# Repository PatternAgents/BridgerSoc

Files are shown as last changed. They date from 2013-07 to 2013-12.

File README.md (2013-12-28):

BridgerSoc
=============

[PatternAgents BridgerSoc  
*PatternAgents BridgerSoc*](http://www.patternagents.com/projects/BridgerSoc.html)

PatternAgents The BridgerSoc uses a Programmable System-on-Chip that can read read inputs from sensors, 
switches, potentiometers, or other analog inputs and use those inputs to control the outputs of your choice.

Features:

  System-on-Chip Standalone Mode (Switches/Analog Inputs Control the Outputs)

  Arduino Uno/Leonardo/Mega/Due Compatible Shield

  Selectable 3.3Volt-5.0Volt Operation

  Sixteen (16) high power darlington control outputs

  Seven (7) analog inputs (sensors, potentiometers)

  Five (5) digital inputs (switches, sensors)

  UART, I2C, SPI, RS-485/DMX Interfaces

  Selectable mode of operation  (Manual or Interface/Shield controlled)

You can read more about the PSoC1 Integrated Circuit used here : http://www.cypress.com/?mpn=CY8C29566-24AXI

[  
*Licensing CC BY-NC-SA 4.0*](http://creativecommons.org/licenses/by-nc-sa/4.0/)

PatternAgents uses the increasingly popular business model called "Dual Licensing" 
in which both the open source software distribution mechanism and traditional commercial software distribution models are combined.

Open Source Projects:        

If you are developing and distributing open source applications under the Creative Commons CC BY-NC-SA 4.0, 
as published by the Creative Commons Foundation, then you are free to use the PatternAgents hardware/software under the CC BY-NC-SA 4.0 license. 
Please note that CC BY-NC-SA 4.0 requires that all modifications to the original code as well as all Derivative Works 
must also be released under the terms of the CC BY-NC-SA 4.0 license.

Closed Source Projects:

If you are developing and distributing traditional closed source or commercial applications, 
you must purchase a PatternAgents commercial use license, 
which is specifically designed for users interested in retaining the proprietary status of their designs and code. 
All PatternAgents commercial licenses expressly supersede the CC BY-NC-SA 4.0 license. 
This means that when you license the PatternAgents software under a commercial license, 
you specifically do not use the software under the CC BY-NC-SA 4.0 license and therefore you are not subject to any of its terms.
        
If you would like to use our designs for your own personal or educational use, have at it! 

Our public design repository is available at <a href="https://github.com/patternagents">Github</a>.

If you would like to produce our designs for commercial use, or as products for sale, 
please contact us to arrange for a Commercial Use license. We have many other designs, 
as well as options and extras that are not released publicly. 
We will also customize designs, firmware, and software for a reasonable fee, just contact us to discuss your requirements.

THIS SOFTWARE IS PROVIDED BY THE CONTRIBUTORS "AS IS" AND WITHOUT ANY EXPRESS OR IMPLIED WARRANTIES, 
INCLUDING, BUT NOT LIMITED TO, THE IMPLIED WARRANTIES OF MERCHANTABILITY AND FITNESS FOR A PARTICULAR PURPOSE ARE DISCLAIMED. 
IN NO EVENT SHALL THE COPYRIGHT OWNER OR CONTRIBUTORS BE LIABLE FOR ANY DIRECT, INDIRECT, INCIDENTAL, SPECIAL, EXEMPLARY, 
OR CONSEQUENTIAL DAMAGES (INCLUDING, BUT NOT LIMITED TO, PROCUREMENT OF SUBSTITUTE GOODS OR SERVICES; LOSS OF USE, DATA, 
OR PROFITS; OR BUSINESS INTERRUPTION) HOWEVER CAUSED AND ON ANY THEORY OF LIABILITY, WHETHER IN CONTRACT, 
STRICT LIABILITY, OR TORT (INCLUDING NEGLIGENCE OR OTHERWISE) ARISING IN ANY WAY OUT OF THE USE OF THIS SOFTWARE, 
EVEN IF ADVISED OF THE POSSIBILITY OF SUCH DAMAGE. 

-------------------------------------------------------------------------------------------

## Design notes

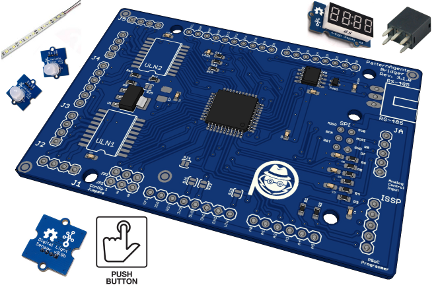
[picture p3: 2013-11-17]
BridgerSoc/images/BridgerSoc_isoc.png

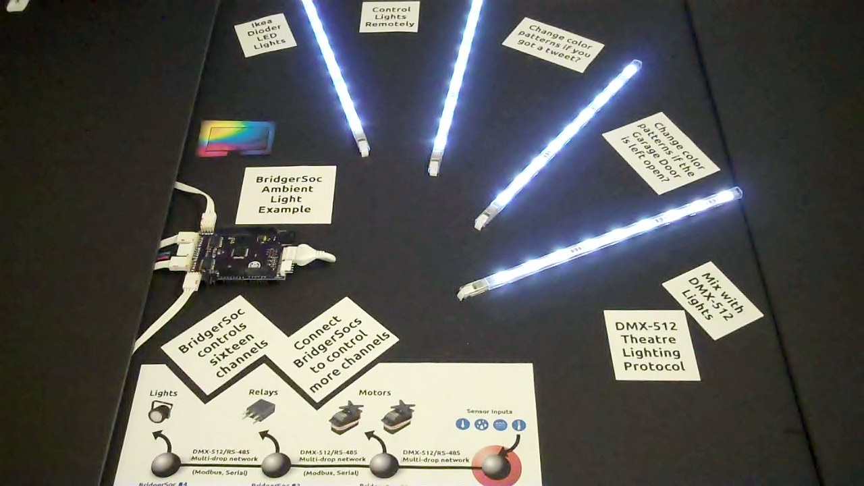
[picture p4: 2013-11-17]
BridgerSoc/images/BridgerSoc1_App2.jpg

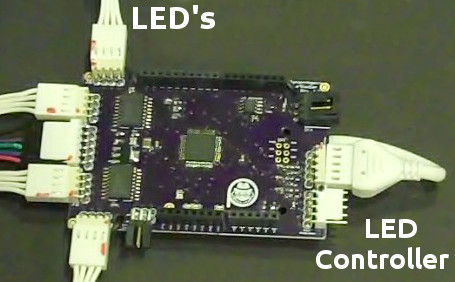
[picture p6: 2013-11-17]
BridgerSoc/images/BridgerSoc1_App1.jpg

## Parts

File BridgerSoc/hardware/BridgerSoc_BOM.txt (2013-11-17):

Partlist BridgerSoc.sch at 10/9/2013 3:49:02 PM

Part   Value              Device               Package               Description                                                                                                                                                                               MF                MPN       OC_FARNELL OC_NEWARK
PCB    PA_LEO_PATTERNMEDW PA_LEO_PATTERNMEDW   PA_LEO_MEDW_PATTERN   PatternAgents BridgerSoc PCB                                                                                                                                                                                                          
C1     0.1uF              CAP0603-CAP          0603-CAP              Capacitor                                                                                                                                                                                                                                 
C2     1uF                CAP0603-CAP          0603-CAP              Capacitor                                                                                                                                                                                                                                 
C3     1uF                CAP0603-CAP          0603-CAP              Capacitor                                                                                                                                                                                                                                 
C4     0.1uF              CAP0603-CAP          0603-CAP              Capacitor                                                                                                                                                                                                                                 
C5     1uF                CAP0603-CAP          0603-CAP              Capacitor                                                                                                                                                                                                                                 
C6     0.1uF              CAP0603-CAP          0603-CAP              Capacitor                                                                                                                                                                                                                                 
C7     10uF               CPOL-EUSMCB          SMC_B                 POLARIZED CAPACITOR, European symbol                                                                                                                                                                                                      
C8     0.1uF              CAP0603-CAP          0603-CAP              Capacitor                                                                                                                                                                                                                                 
C9     0.1uF              CAP0603-CAP          0603-CAP              Capacitor                                                                                                                                                                                                                                 
C10    0.1uF              CAP0603-CAP          0603-CAP              Capacitor                                                                                                                                                                                                                                 
FID1   FIDUCIAL1.5X3      FIDUCIAL1.5X3        FIDUCIAL-1.5X3        Fiducial Alignment Points                                                                                                                                                                                                                 
FID2   FIDUCIAL1.5X3      FIDUCIAL1.5X3        FIDUCIAL-1.5X3        Fiducial Alignment Points                                                                                                                                                                                                                 
FID3   FIDUCIAL1.5X3      FIDUCIAL1.5X3        FIDUCIAL-1.5X3        Fiducial Alignment Points                                                                                                                                                                                                                 
FID4   FIDUCIAL1.5X3      FIDUCIAL1.5X3        FIDUCIAL-1.5X3        Fiducial Alignment Points                                                                                                                                                                                                                 
ISSP                      M05PTH               1X05                  Header 5                                                                                                                                                                                                                                  
J1                        M04PTH               1X04                  Header 4                                                                                                                                                                                                                                  
J2                        M04PTH               1X04                  Header 4                                                                                                                                                                                                                                  
J3                        M06SIP               1X06                  Header 6                                                                                                                                                                                                                                  
J4                        M04PTH               1X04                  Header 4                                                                                                                                                                                                                                  
J5                        M04PTH               1X04                  Header 4                                                                                                                                                                                                                                  
JA                        M05PTH               1X05                  Header 5                                                                                                                                                                                                                                  
JP1                       M03PTH               1X03                  Header 3                                                                                                                                                                                                                                  
JP2                       M03PTH               1X03                  Header 3                                                                                                                                                                                                                                  
LED1                      LED0603              LED-0603              LEDs                                                                                                                                                                                                                                      
R1     4.7K               RESISTORR0603        R0603                 RESISTOR, American symbol                                                                                                                                                                                                                 
R2     4.7K               RESISTORR0603        R0603                 RESISTOR, American symbol                                                                                                                                                                                                                 
R3     10K                RESISTORR0603        R0603                 RESISTOR, American symbol                                                                                                                                                                                                                 
R4     1K                 RESISTORR0603        R0603                 RESISTOR, American symbol                                                                                                                                                                                                                 
R5     10K                RESISTORR0603        R0603                 RESISTOR, American symbol                                                                                                                                                                                                                 
R6     1K                 RESISTORR0603        R0603                 RESISTOR, American symbol                                                                                                                                                                                                                 
R7     10K                RESISTORR0603        R0603                 RESISTOR, American symbol                                                                                                                                                                                                                 
R8     1K                 RESISTORR0603        R0603                 RESISTOR, American symbol                                                                                                                                                                                                                 
R9     240                RESISTORR0603        R0603                 RESISTOR, American symbol                                                                                                                                                                                                                 
R10    390                RESISTORR0603        R0603                 RESISTOR, American symbol                                                                                                                                                                                                                 
R11    330                RESISTORR0603        R0603                 RESISTOR, American symbol                                                                                                                                                                                                                 
R12    4.7K               RESISTORR0603        R0603                 RESISTOR, American symbol                                                                                                                                                                                                                 
R13    4.7K               RESISTORR0603        R0603                 RESISTOR, American symbol                                                                                                                                                                                                                 
R14    1K                 RESISTORR0603        R0603                 RESISTOR, American symbol                                                                                                                                                                                                                 
RS-485 70553-02           70553-02             70553-02              Molex SL Modular Connectors - 3 PIN                                                                                                                                                                                                       
RTERM  120                RESISTOR_SFE0603-RES 0603-RES              Resistor                                                                                                                                                                                                                                  
SJ1    SOLDERJUMPERNO     SOLDERJUMPERNO       SJ_2S-NO              Solder Jumper                                                                                                                                                                                                                             
SJ2    SOLDERJUMPERNO     SOLDERJUMPERNO       SJ_2S-NO              Solder Jumper                                                                                                                                                                                                                             
SJ3    SOLDERJUMPERNO     SOLDERJUMPERNO       SJ_2S-NO              Solder Jumper                                                                                                                                                                                                                             
SJ4    SOLDERJUMPERNO     SOLDERJUMPERNO       SJ_2S-NO              Solder Jumper                                                                                                                                                                                                                             
SJ5    SOLDERJUMPERNO     SOLDERJUMPERNO       SJ_2S-NO              Solder Jumper                                                                                                                                                                                                                             
TVS1   SP1001-02JTG       SP1001-02JTG         SC70-3                Littelfuse SP1001-02JTG TVS Diode Array                                            
U1     V_REG_317SMD       V_REG_317SMD         SOT223                Voltage Regulator                                                                                                                                                                                                                         
U2     CY8C29566-44PIN    CY8C29566-44PIN      TQFP-10X10-44         Cypress PSoC® 1 - PSOC, M8C Based                                                                                                                                                                                  
U3     SN65176D           SN65176D             SO-08                 DIFFERENTIAL BUS TRANSCEIVER                                                                                                                                                              TEXAS INSTRUMENTS SN65176BD 9589970    08F5891  
ULN1                      ULN2803SOICW         SO18L                 Darlington Driver                                                                                                                                                                                                                         
ULN2                      ULN2803SOICW         SO18L                 Darlington Driver                                                                                                                                                                                                                         
JA1                       M08PTH               1X08                  Arduino1                                                                                                                                                                                                                                  
JA2                       M06PTH               1X06                  Arduino2                                                                                                                                                                                                                                  
JA3                       M08PTH               1X08                  Arduino3                                                                                                                                                                                                                                  
JA4                       M10PTH               1X10                  Arduino4

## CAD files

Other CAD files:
BridgerSoc/eagleUp/BridgerSoc.skp

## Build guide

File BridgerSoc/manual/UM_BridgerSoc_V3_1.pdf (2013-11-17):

BridgerSoc1—Getting Started Guide

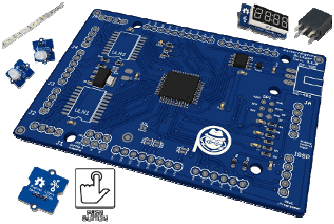
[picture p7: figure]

Page 1 | www.patternagents.com

## BridgerSoc1

## Getting Started Guide

Copyright 2011, 2012, 2013 www.patternagents.com

http://www.patternagents.com/products.html

Revision 3.1.11
PCD #272A

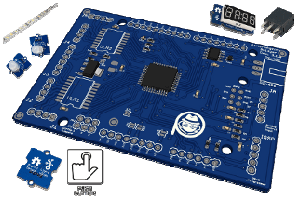
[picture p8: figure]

Page 2 | www.patternagents.com

## BridgerSoc1

Overview | 2
Getting Started | 2
Operating Modes | 6
Schematic and Layout | 14
PSoC Pin Assignment | 20
BridgerSoc1 PCB Pin Assignment | 21
Custom Configuration Jumpers | 22
Frequently Asked Questions (FAQ) | 24
Example Project | 12

Contents :

Page 3 | www.patternagents.com

### Congratulations on your purchase of the “BridgerSoc1” board!

### The PatternAgents “BridgerSoc1” board has the following features :

### - System-on-Chip Standalone Mode (Switches/Analog Inputs Control the Outputs)

### - Arduino Uno/Leonardo/Mega/Due Compatible Shield

### - Selectable 3.3Volt-5.0Volt Operation

### - Sixteen (16) high power darlington control outputs

### - Seven (7) analog inputs (sensors, potentiometers)

### - Five (5) digital inputs (switches, sensors)

### - UART, I2C, SPI, RS-485/DMX Interfaces

### - Selectable mode of operation (Manual or Interface/Shield controlled)

### Overview :

BridgerSoc1 has sixteen (16) programmable digital blocks, and twelve (12)
progammable analog blocks that come pre-programmed for a variety of uses, so it is ready to use right out of the box. It also includes a Command Line Interface (CLI) that gives you the ability to control it right from a terminal or the programming language of your choice, mak-ing it very easy to get started.
Using a set of configuration jumpers, you can interface to the BridgerSoc1 using
simple switches or sensors, so anyone can use it without having to learn how to
program. If you want to control Bridger from a program you can use the UART (CLI), I2C/Two-Wire Bus, or the SPI interface - giving you the maximum flexibility to configure your other shields without I/O conflicts.

Stack-Thru Models (optional request):
As an option, PatternAgents “BridgerSoc1” boards can populated with “Stack-Thru” connectors, which allow Arduino Shields to be added to the top or bottom of the Arduino board stack.

NOTE: Always make sure the stacking pins don’t contact a metal surface (like a metal table).

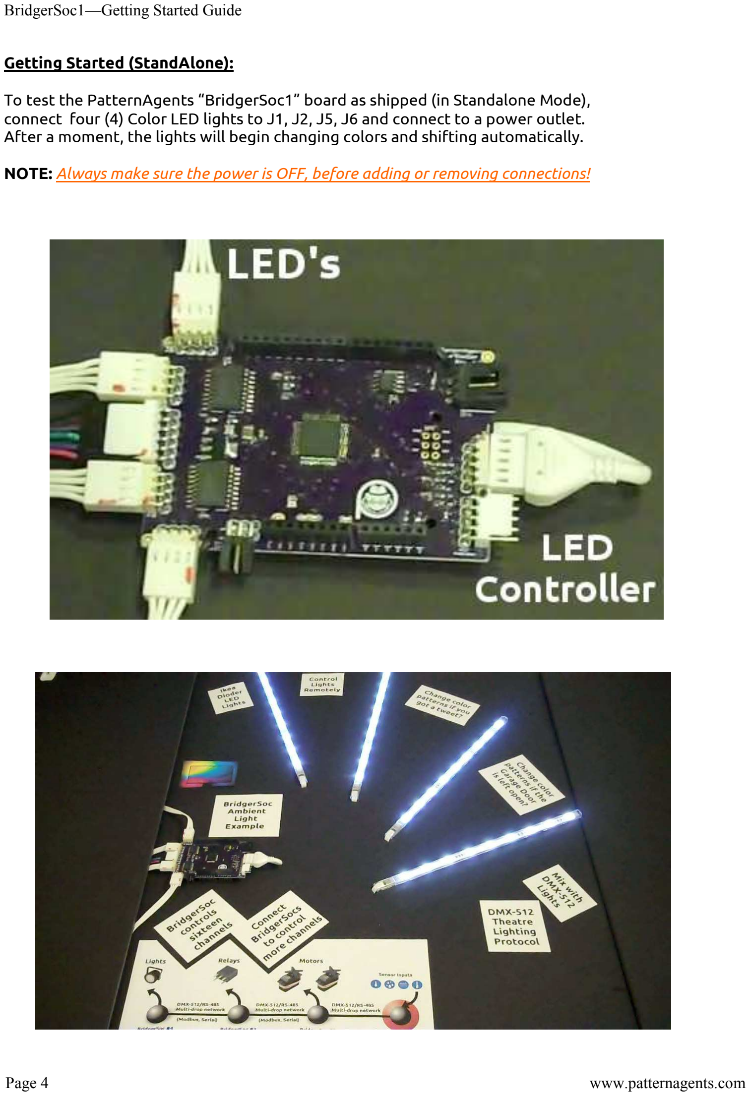
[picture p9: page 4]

Page 4 | www.patternagents.com

Getting Started (StandAlone):

To test the PatternAgents “BridgerSoc1” board as shipped (in Standalone Mode), connect four (4) Color LED lights to J1, J2, J5, J6 and connect to a power outlet. After a moment, the lights will begin changing colors and shifting automatically.

NOTE: Always make sure the power is OFF, before adding or removing connections!

Page 5 | www.patternagents.com

Getting Started (Arduino):

To connect the PatternAgents “BridgerSoc1” board to an Arduino CPU, carefully align the pins between the two boards and gently press together to connect.

NOTE: Always make sure the power is OFF, before adding or removing connections!

Arduino Serial Mode (Mode 0);

Make sure that all three (3) jumpers are connected between JP1 and JP2 to select Mode 0. Connect the Arduino USB interface to your host computer and open a “Hyper-terminal” or other Terminal emulation program to the serial port for your Arduino (COMx:).
Set the Terminal emulation program to 9600 Baud , N, 8, 1 (which is usually the default).
Set the Terminal emulation program to “Echo” so that you can see the characters typed.

The Sixteen Lighting Channels reside from a default DMX address of 40 to 55 (decimal). So the User would set the lighting channels all to maximum brightness using :

> <DMX> 40 255<CR>
> <DMX> 41 255<CR>
> <DMX> 42 255<CR>
> ...
> <DMX> 55 255<CR>

To read the setting of a DMX channel, just use the question mark for data : > <DMX> 40 ?<CR>

and the BridgerSoc1 will respond :
> <DMX> 40 255<CR>

CLI Help : (enter ?)

> ?
Help Topics
——————-
…

Page 6 | www.patternagents.com

BridgerSoc1 Operating Modes :

The BridgerSoc1 has three (3) Configuration Jumpers which select one (1) of eight (8) operating modes, namely :

0 : 000 : UART CLI Mode
1 : 001 : I2C Arduino Mode
2 : 010 : I2C Leonardo Mode
3 : 011 : SPI Mode
4 : 100 : Test Mode
5 : 101 : DMX-512 Slave Mode
6 : 110 : Bike Light Mode : (Run/Stop/Left-Turn/Right-Turn) 7 : 111 : Standalone Mode - Dioder Manual Control

The Configuration Jumpers are labeled JP1/JP2, pins 1 thru 3.
The BridgerSoc1 is shipped in “Test Mode (4)” so that it automatically Starts changing the lighting colors in a shifting pattern.

Page 7 | www.patternagents.com

BridgerSoc1 Operating Mode O : UART CLI Mode :

# Mode 0 - UART CLI Mode

# In this mode the BridgerSoc1 communicates with a host using a # Command Line Interface via a UART serial interface,

# using Arduino Pins D0 (TXD) & D1 (RXD)

# The Arduino default of 9600 Baud, 8 Bits, No Parity, 1 Stop Bit is used.

# Open a “HyperTerminal” or other program interface to the Arduino serial Port.

# The Sixteen Lighting Channels reside from a default DMX address of 40 to 55 (decimal). # So the User would set the lighting channels all to maximum brightness using :

# | > <DMX> 40 255<CR>

# | > <DMX> 41 255<CR>

# | > <DMX> 42 255<CR>

# | > ...

# | > <DMX> 55 255<CR>

# | To read the setting of a DMX channel, just use the question mark for data :

# | > <DMX> 40 ?<CR>

# | and the BridgerSoc1 will respond :

# | > <DMX> 40 255<CR>

# CLI Help : (enter ?)

# | > ?

# | Help Topics

# | ——————-

# | …

Page 8 | www.patternagents.com

BridgerSoc1 Operating Mode 1 : I2C Arduino Mode :

# Mode 1 - I2C Arduino Mode

# In this mode the BridgerSoc1 communicates with an Arduino host using # the original I2C Pins for the Arduino Uno, A4 & A5.

# The Arduino default of 400K speed I2C Bus is used.

# Open a “HyperTerminal” or other program interface to the Arduino serial Port.

# The Sixteen Lighting Channels reside from a default I2C address of 40 to 55 (decimal). # So the User would set the lighting channels all to maximum brightness using :

# | > <I2C_Write> 40 255<CR>

# | > <I2C_Write> 41 255<CR>

# | > <I2C_Write> 42 255<CR>

# | > ...

# | > <I2C_Write> 55 255<CR>

BridgerSoc1 Operating Mode 2 : I2C Leonardo Mode :

# Mode 2 - I2C Leonardo Mode

# In this mode the BridgerSoc1 communicates with an Arduino host using # the I2C Pins for the Arduino Leonardo, SCL &SDA.

# The Arduino default of 400K speed I2C Bus is used.

# Open a “HyperTerminal” or other program interface to the Arduino serial Port.

# The Sixteen Lighting Channels reside from a default I2C address of 40 to 55 (decimal). # So the User would set the lighting channels all to maximum brightness using :

# | > <I2C_Write> 40 255<CR>

# | > <I2C_Write> 41 255<CR>

# | > <I2C_Write> 42 255<CR>

# | > ...

# | > <I2C_Write> 55 255<CR>

Page 9 | www.patternagents.com

BridgerSoc1 Operating Mode 3 : SPI Mode :

# Mode 3 - SPI Mode

# In this mode the BridgerSoc1 communicates with an Arduino host using

# the SPI Pins for the Arduino Leonardo, P13, P12, P11, & P10.

# The Sixteen Lighting Channels reside from a default SPI address of 40 to 55 (decimal). # So the User would set the lighting channels all to maximum brightness using :

# | > <SPI_Write> 40 255<CR>

# | > <SPI_Write> 41 255<CR>

# | > <SPI_Write> 42 255<CR>

# | > ...

# | > <SPI_Write> 55 255<CR>

BridgerSoc1 Operating Mode 4 : Test Mode :

# Mode 4 - Test Mode

# | In this mode the BridgerSoc1 operates standalone,

# | and cycles random colors through all of the lighting channels.

# The BridgerSoc1 will ignore all other inputs in this mode.

Page 10 | www.patternagents.com

BridgerSoc1 Operating Mode 5 : DMX-512 Slave Mode :

# Mode 5 - DMX-512 Slave Mode

# In this mode the BridgerSoc1 communicates with a DMX-512 Universe/Host using # the DMX-512/RS-485 connector, labeled “DMX-512”.

# The DMX-512 default of 250k Baud, 8 Bits, No Parity, 1 Stop Bit is used.

# The Sixteen Lighting Channels reside from a default DMX address of 40 to 55 (decimal). # So the User would set the lighting channels all to maximum brightness using :

# | > <DMX> 40 255<CR>

# | > <DMX> 41 255<CR>

# | > <DMX> 42 255<CR>

# | > ...

# | > <DMX> 55 255<CR>

Page 11 | www.patternagents.com

BridgerSoc1 Operating Mode 6 : DMX-512 Slave Mode :

# Mode 6 - Bike Light Controller Mode

# In this mode the BridgerSoc1 reads a number of input switches, # located on the handlebars or the steering wheel column of a

# Light Electric Vehicle (LEV),

# via the D12/D11/D10/A3/A2/A1/A0 pin inputs.

# The control inputs have internal pullup resistors,

# so that a switch closed (on) should connect them to ground. #

# Handlebar Switch mapping is as follows :

# | Arduino | Pin Function | PSoC

# | Pin | Pin

# | D13 | : Arduino LED (input) P1_3

# | D12 | : Run Light/On Switch P4_1

# | D11 | : Horn Pushbutton | P2_1

# | D10 | : Mode Pushbutton | P2_7

# | A3 | : Right Turn Switch | P0_2

# | A2 | : Left Turn Switch | P0_3

# | A1 | : Brake Switch | P0_5

# | A0 | : Throttle/ADC Input | P0_4

# | LED Light output Mapping is as follows :

# | J1 | : Left Rear Running/Turn LED

# | J2 | : Left Front Running/Turn LED

# | J3 | : Front Headlight/Body LEDs

# | J4 | : Ikea Color Wheel Controller Input

# | J5 | : Right Front Running/Turn LED

# | J6 | : Right Rear Running/Turn LED

# In this mode, all other inputs are ignored, the physical switches control the lights. #

BridgerSoc1 Operating Mode 7 : Manual Controller Mode :

# Mode 7 - Manual Controller Mode

# In this mode the BridgerSoc1 is controlled by the Ikea Dioder Manual Control/Box, # which include it’s built-in color changing programs.

Page 12 | www.patternagents.com

BridgerSoc1— Example Project :

(Coming…)

Page 13 | www.patternagents.com

BridgerSoc1— Example Project :

(Coming…)

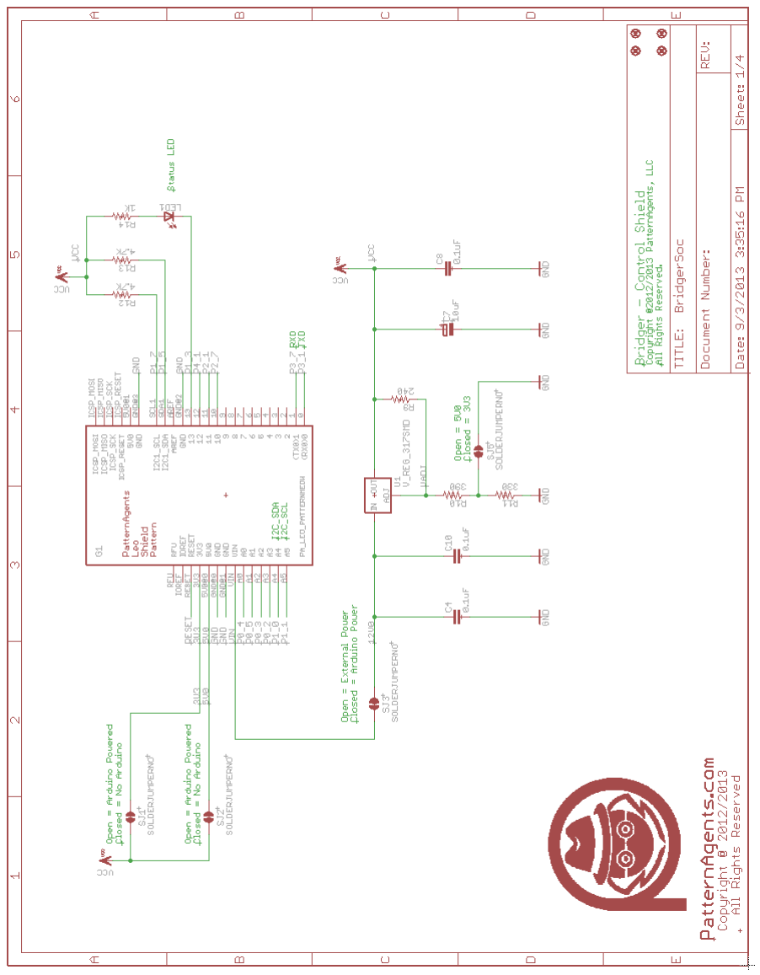
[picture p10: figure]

Page 14 | www.patternagents.com

### BridgerSoc1—Schematic Drawings

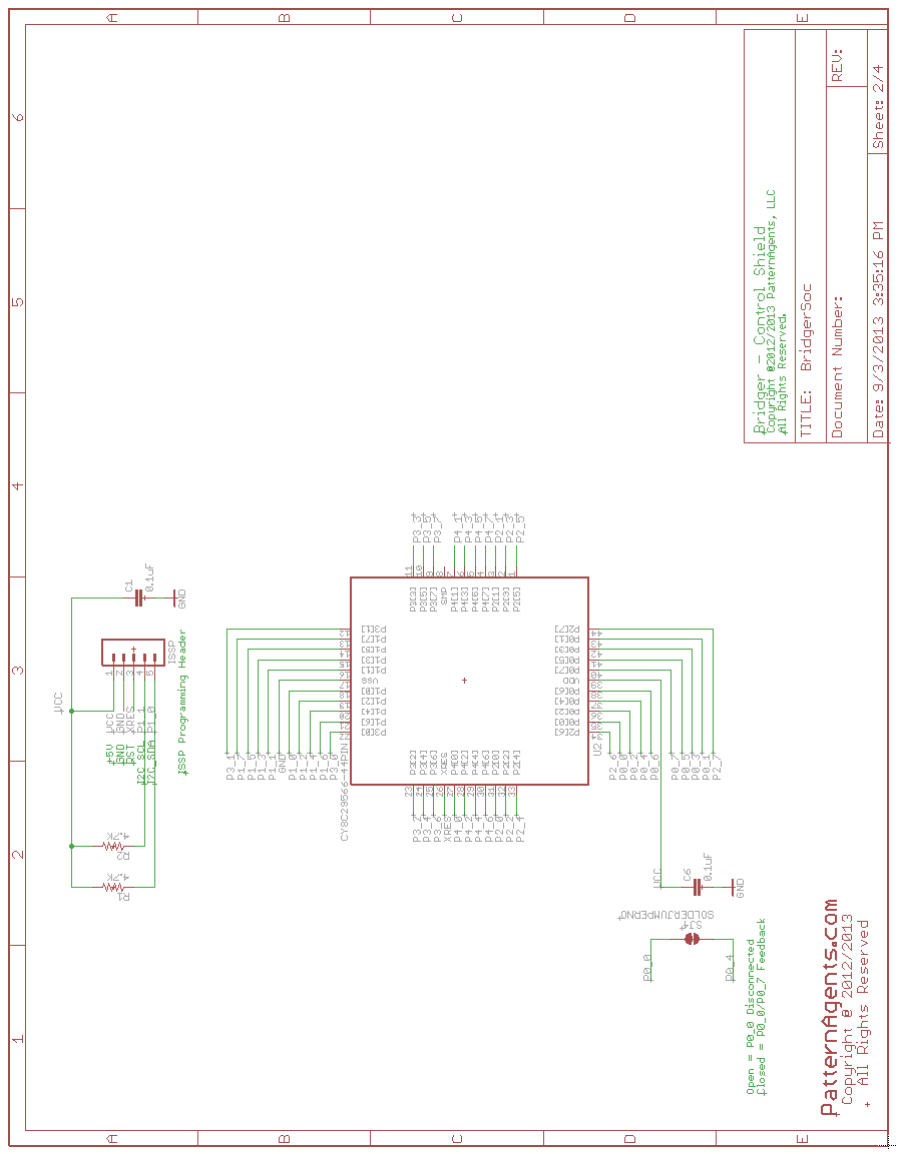
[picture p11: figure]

Page 15 | www.patternagents.com

### BridgerSoc1—Schematic Drawings

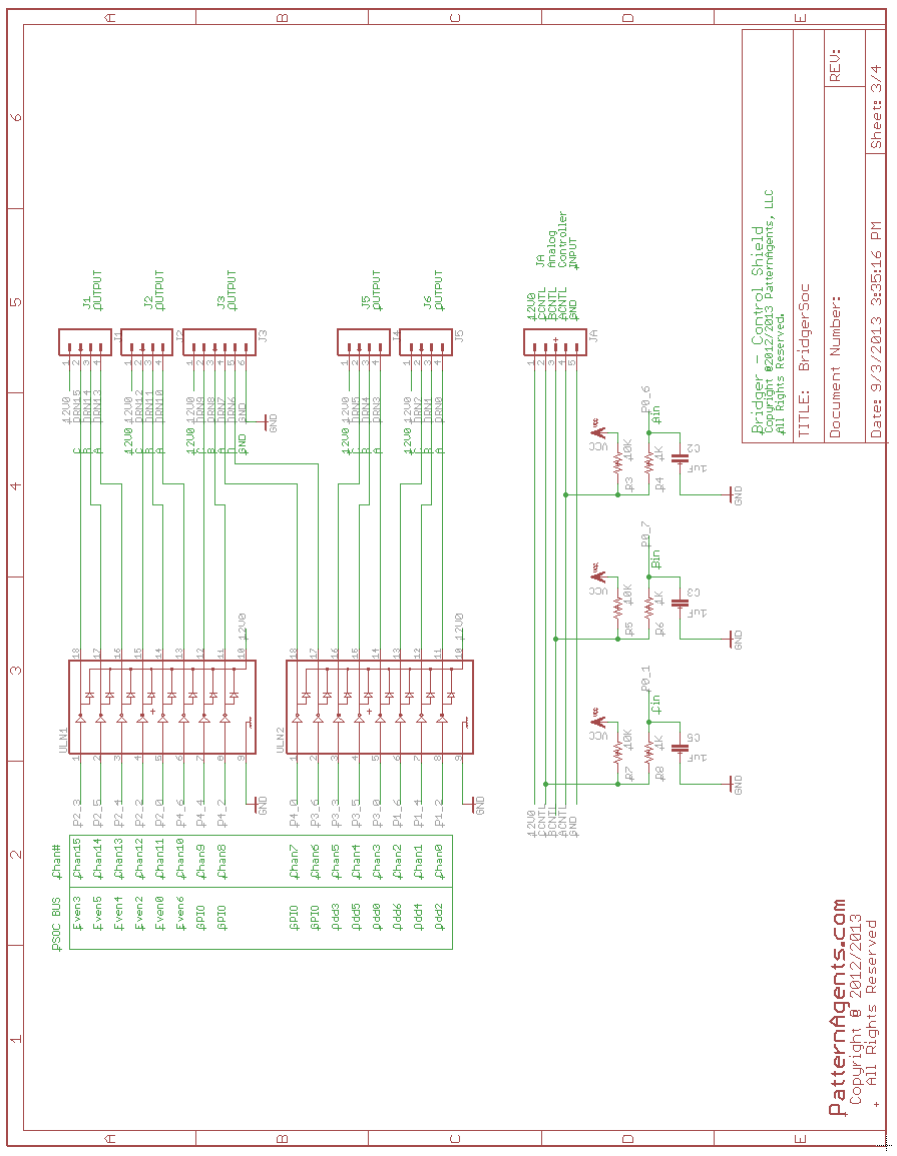
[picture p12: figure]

Page 16 | www.patternagents.com

### BridgerSoc1—Schematic Drawings

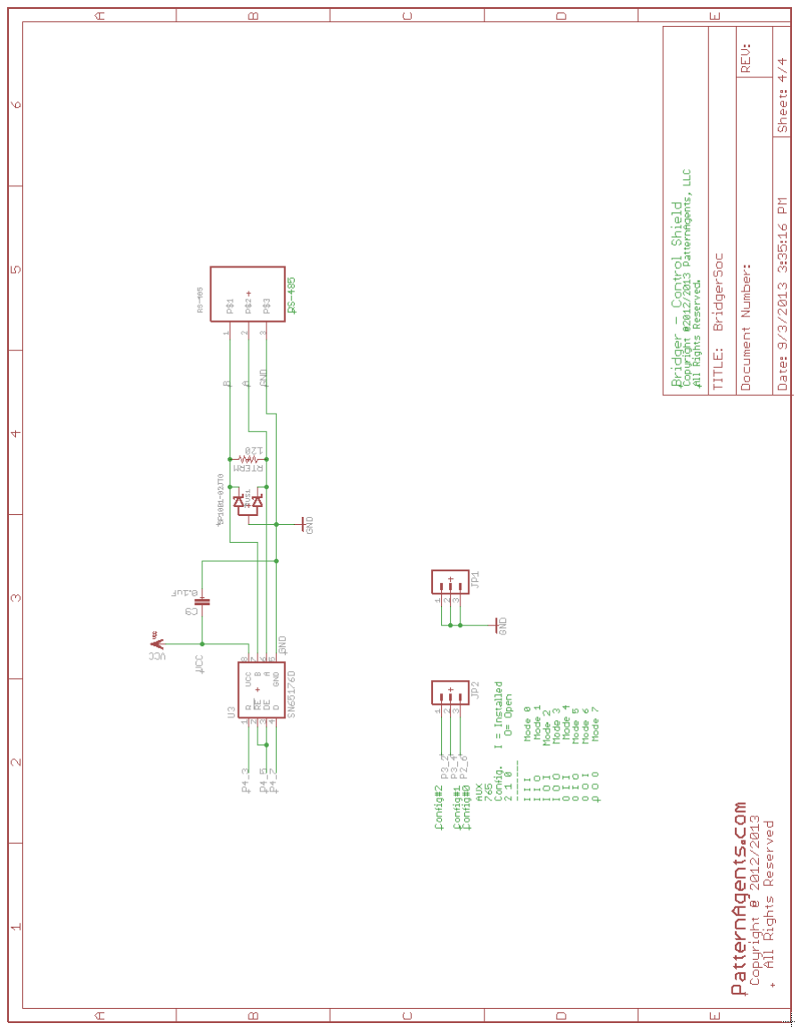
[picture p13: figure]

Page 17 | www.patternagents.com

### BridgerSoc1—Schematic Drawings

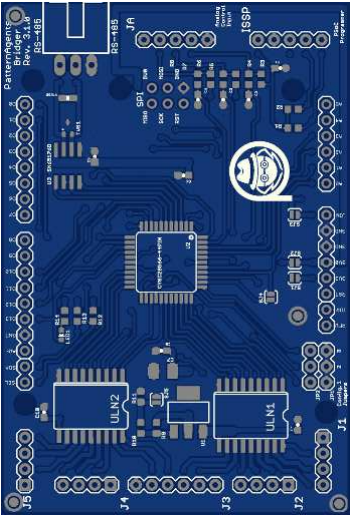
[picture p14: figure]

Page 18 | www.patternagents.com

### BridgerSoc1—PCB Top View

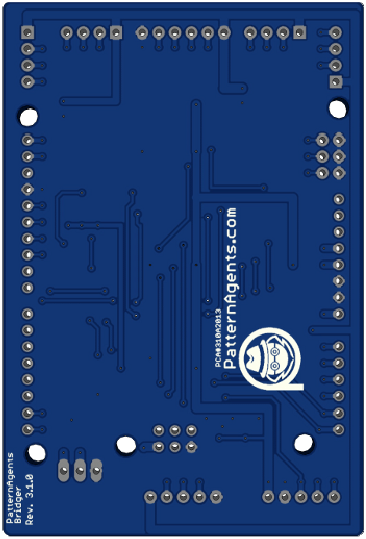
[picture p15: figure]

Page 19 | www.patternagents.com

### BridgerSoc1—PCB Bottom View

Page 20 | www.patternagents.com

BridgerSoc1— PSoC I/O Pin Assignment :

# Pin Assignments :

# Pin P0.0 ( 0 ) - SJ4/P0_4 Feedback (RFU) # Pin P0.1 ( 1 ) - Green Manual Control

# Pin P0.2 ( 2 ) - A3

# Pin P0.3 ( 3 ) - A2

# Pin P0.4 ( 4 ) - A0

# Pin P0.5 ( 5 ) - A1

# Pin P0.6 ( 6 ) - Red Manual Control # Pin P0.7 ( 7 ) - Blue Manual Control

# Pin P1.0 ( 8 ) - ISSP/I2C-SDA/A4 # Pin P1.1 ( 9 ) - ISSP/I2C-SCL/A5

# Pin P1.2 ( 10 ) - LED0/SSDM0

# Pin P1.3 ( 11 ) - D13/LED_D13

# Pin P1.4 ( 12 ) - LED1/SSDM1

# Pin P1.5 ( 13 ) - I2C-SDA

# Pin P1.6 ( 14 ) - LED2/SSDM2 # Pin P1.7 ( 15 ) - I2C-SCL

# Pin P2.0 ( 16 ) - LED11/SSDM11 # Pin P2.1 ( 17 ) - D11

# Pin P2.2 ( 18 ) - LED12/SSDM12 # Pin P2.3 ( 19 ) - LED15/SSDM15 # Pin P2.4 ( 20 ) - LED13/SSDM13 # Pin P2.5 ( 21 ) - LED14/SSDM14 # Pin P2.6 ( 22 ) - CFG3

# Pin P2.7 ( 23 ) - D10

# Pin P3.0 ( 24 ) - LED3/SSDM3 # Pin P3.1 ( 25 ) - D0/UART1-TXD # Pin P3.2 ( 26 ) - CFG1

# Pin P3.3 ( 27 ) - LED5/SSDM5 # Pin P3.4 ( 28 ) - CFG2

# Pin P3.5 ( 29 ) - LED4/SSDM4 # Pin P3.6 ( 30 ) - LED6

# Pin P3.7 ( 31 ) - D1/UART1-RXD #

# Pin P4.0 ( 32 ) - LED7

# Pin P4.1 ( 33 ) - D12

# Pin P4.2 ( 34 ) - LED8

# Pin P4.3 ( 35 ) - DMX-TXD

# Pin P4.4 ( 36 ) - LED9

# Pin P4.5 ( 37 ) - DMX-DIR

# Pin P4.6 ( 38 ) - LED10/SSDM10 # Pin P4.7 ( 39 ) - DMX-RXD

Page 21 | www.patternagents.com

BridgerSoc1— PCB Pin Assignment :

J1/J2/J4/J5 | Pin# | 1—VIN (12 VDC) 2—Green LED Output 3– Blue LED Output 4—Red LED Output
J3 | Pin# | 1—VIN (12 VDC) 2—Green LED Output 3– Blue LED Output 4—Red LED Output 5—Yellow/White LED Output 6—Ground
JA | Pin# | 1—VIN (12 VDC) 2—Green LED In 3– Blue LED In 4—Red LED In 5—Ground

RS-485/DMX-512
| Pin# | 1– B 2—A 3—Ground

Page 22 | www.patternagents.com

I/O Configuration :

BridgerSoc1 I/O Voltage Configuration :
The BridgerSoc1 boards have the ability to configure I/O signals for different voltage levels, and can be configured for either 3.3V or 5.0V volt levels. It is important to determine if your Arduino re-quires 3.3V or 5.0V volt levels, and configure your BridgerSoc1 board correctly. Refer to the manual for your Arduino board for the correct voltage settings.

Solder Jumper J5 Installed—3.3V operation
Solder Jumper J5 Removed—5.0V operation (factory default setting)

NOTE: Always make sure voltages are set correctly for your Arduino shield or you can damage it.

External VIN/5V0/3V3 Power Configuration :

The BridgerSoc1 can either get it power from an Arduino CPU, or have it’s own power supplied independently. This allows the BridgerSoc1 power input to be different than the Arduino VIN.
The default setting is that no power is connected to the Ardunio (they are independently powered). In order to change those setting, install solder jumpers as follows :

Solder Jumper J3 Installed—Arduino and BridgerSoc1 share VIN
Solder Jumper J3 Removed—Arduino and BridgerSoc1 have separate VIN

Solder Jumper J2 Installed—Arduino and BridgerSoc1 share 5.0V power
Solder Jumper J2 Removed—Arduino and BridgerSoc1 have separate 5.0V power

Solder Jumper J1 Installed—Arduino and BridgerSoc1 share 3.3V power
Solder Jumper J1 Removed—Arduino and BridgerSoc1 have separate 3.3V power

NOTE: Install either J1 or J2 , but not both, that would short 3.3v and 5V together.

Page 23 | www.patternagents.com

(This page intentionally left blank)

FAQ :

1) Can I use the “BridgerSoc1” with an “Arduino” CPU Board?

Yes. Any “Host” Arduino CPU board can be connected on the top/bottom side of the “BridgerSoc1” Board depending on what connector you install
(i.e. female only, or stack-through connectors). This allows for multi-CPU/multi-processor/ multiple architecture (i.e. big/little) configurations.

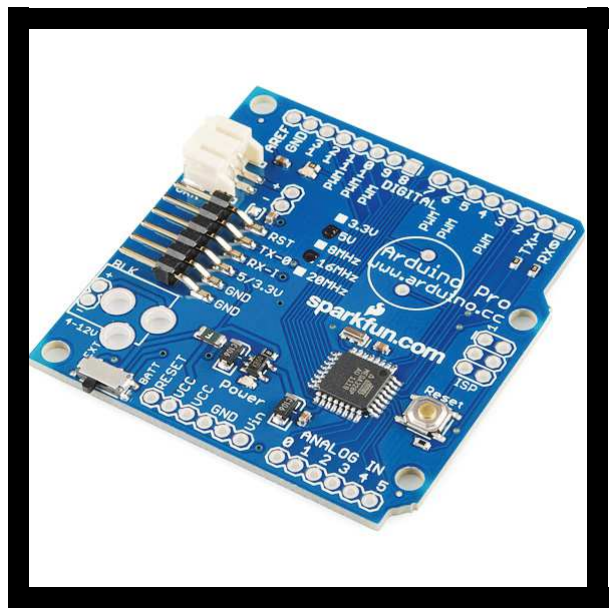
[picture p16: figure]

2) Can I use the “BridgerSoc1” with “Arduino” prototyping supplies ?

Yes. Any Arduino prototyping board can be connected on the top/bottom side of the “CPM-S to Ardu ino Shield Adaptor” Board depending on what connectors you install (i.e. male/female only, or stack- through).

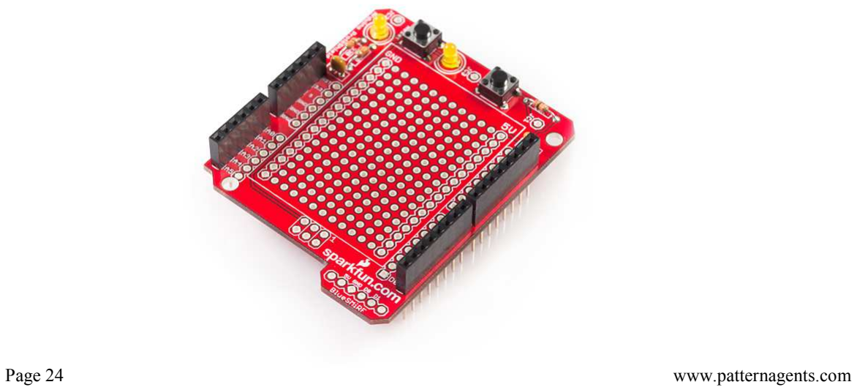
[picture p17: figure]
Page 24; www.patternagents.com

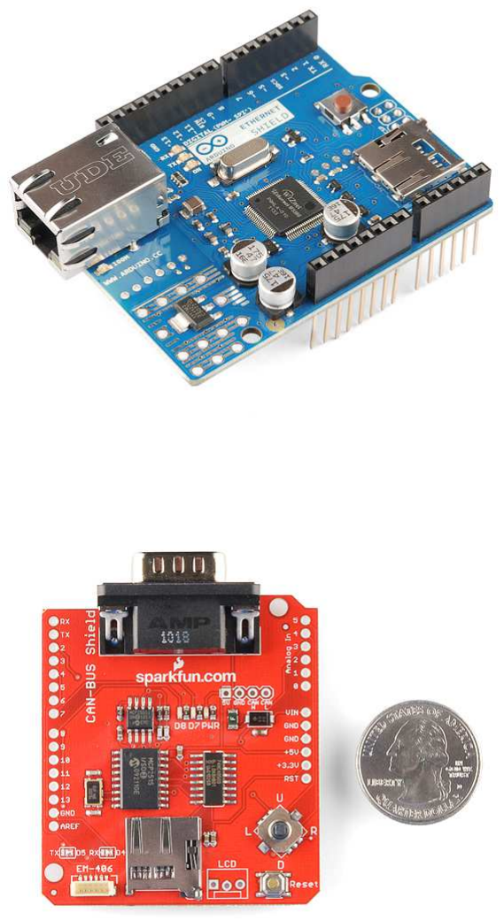
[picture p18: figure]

Page 25 | www.patternagents.com
5) Can I use the “BridgerSoc1” with other “Arduino” shields ?

Yes. (Almost) any Arduino shield board can be connected on the top/bottom side of the “BridgerSoc1” Board depending on what connectors you install
(i.e. male/female only, or stack-through)

Arduino Ethernet Shield :

Image from :
https://www.sparkfun.com/products/9026

Arduino CAN-BUS Shield :

Image from :
https://www.sparkfun.com/products/10039

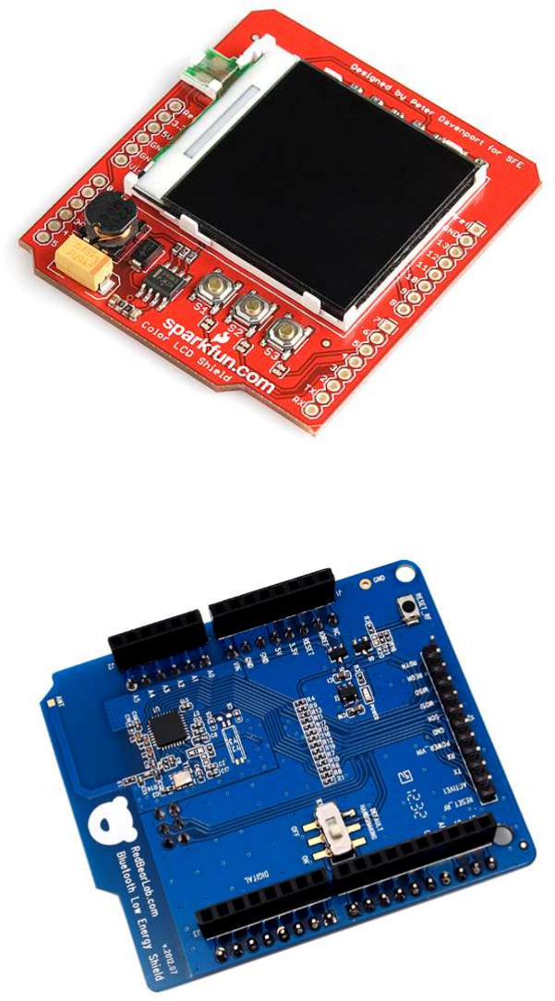
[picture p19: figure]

Page 26 | www.patternagents.com

Arduino Color LCD Shield :

Image from :
https://www.sparkfun.com/products/9363

provides an easy method of connecting the popular Nokia 6100 LCD to your PSoC.

Arduino BlueTooth LE Shield :

Image from :
https://www.seedstudio.com

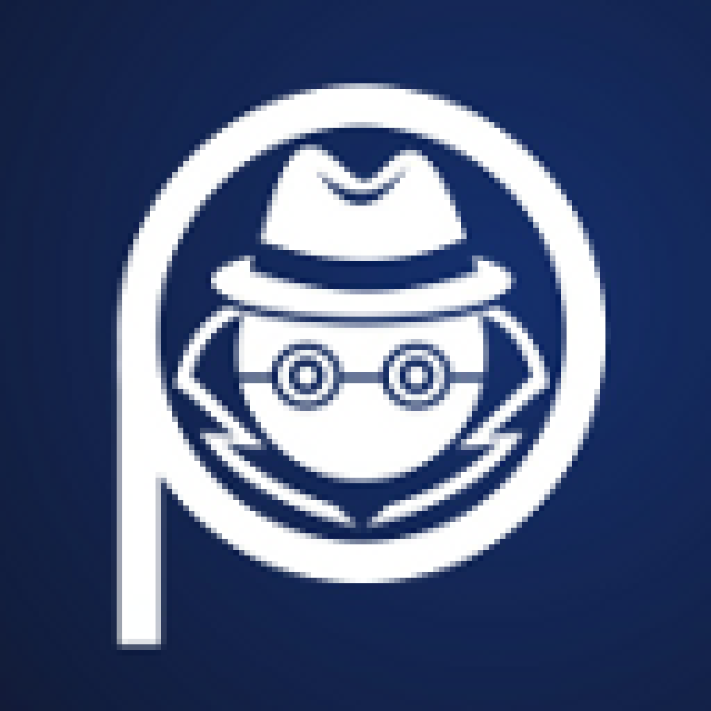
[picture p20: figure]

Page 27 | www.patternagents.com Copyright 2011, 2012, 2013 www.patternagents.com

# PatternAgents provides community and commerce for electronics designers so that they can collaborate using shared

design patterns, practices, and resources; connect with others in the industry, conceptualize and create new ideas,

# commercialize their designs, and keep up

on the latest technologies and concepts.

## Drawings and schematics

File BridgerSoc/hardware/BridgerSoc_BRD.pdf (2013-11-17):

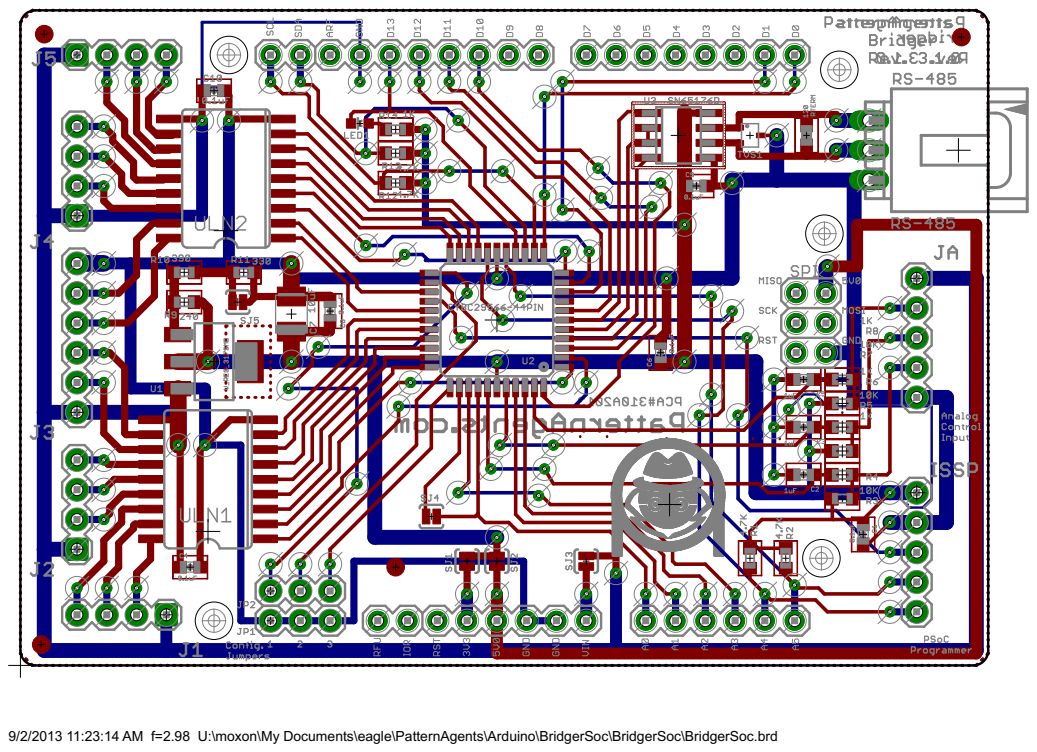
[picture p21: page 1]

9/2/2013 11:23:14 AM f=2.98 U:\moxon\My Documents\eagle\PatternAgents\Arduino\BridgerSoc\BridgerSoc\BridgerSoc.brd

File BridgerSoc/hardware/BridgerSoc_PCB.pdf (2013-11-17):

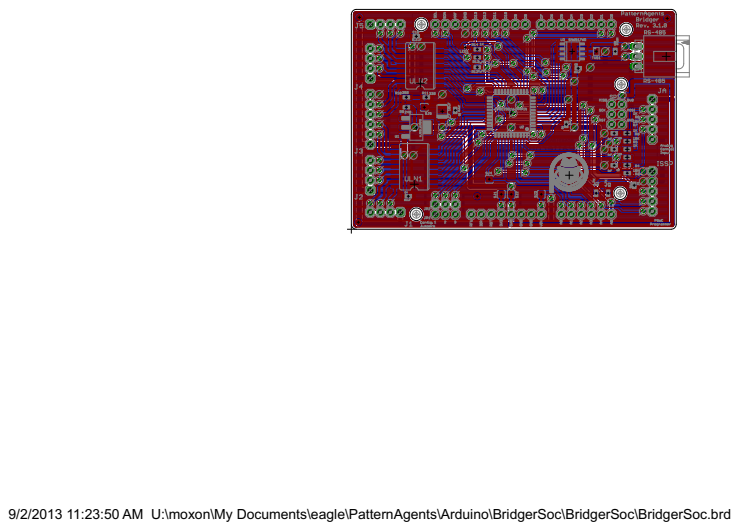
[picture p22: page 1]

9/2/2013 11:23:50 AM U:\moxon\My Documents\eagle\PatternAgents\Arduino\BridgerSoc\BridgerSoc\BridgerSoc.brd

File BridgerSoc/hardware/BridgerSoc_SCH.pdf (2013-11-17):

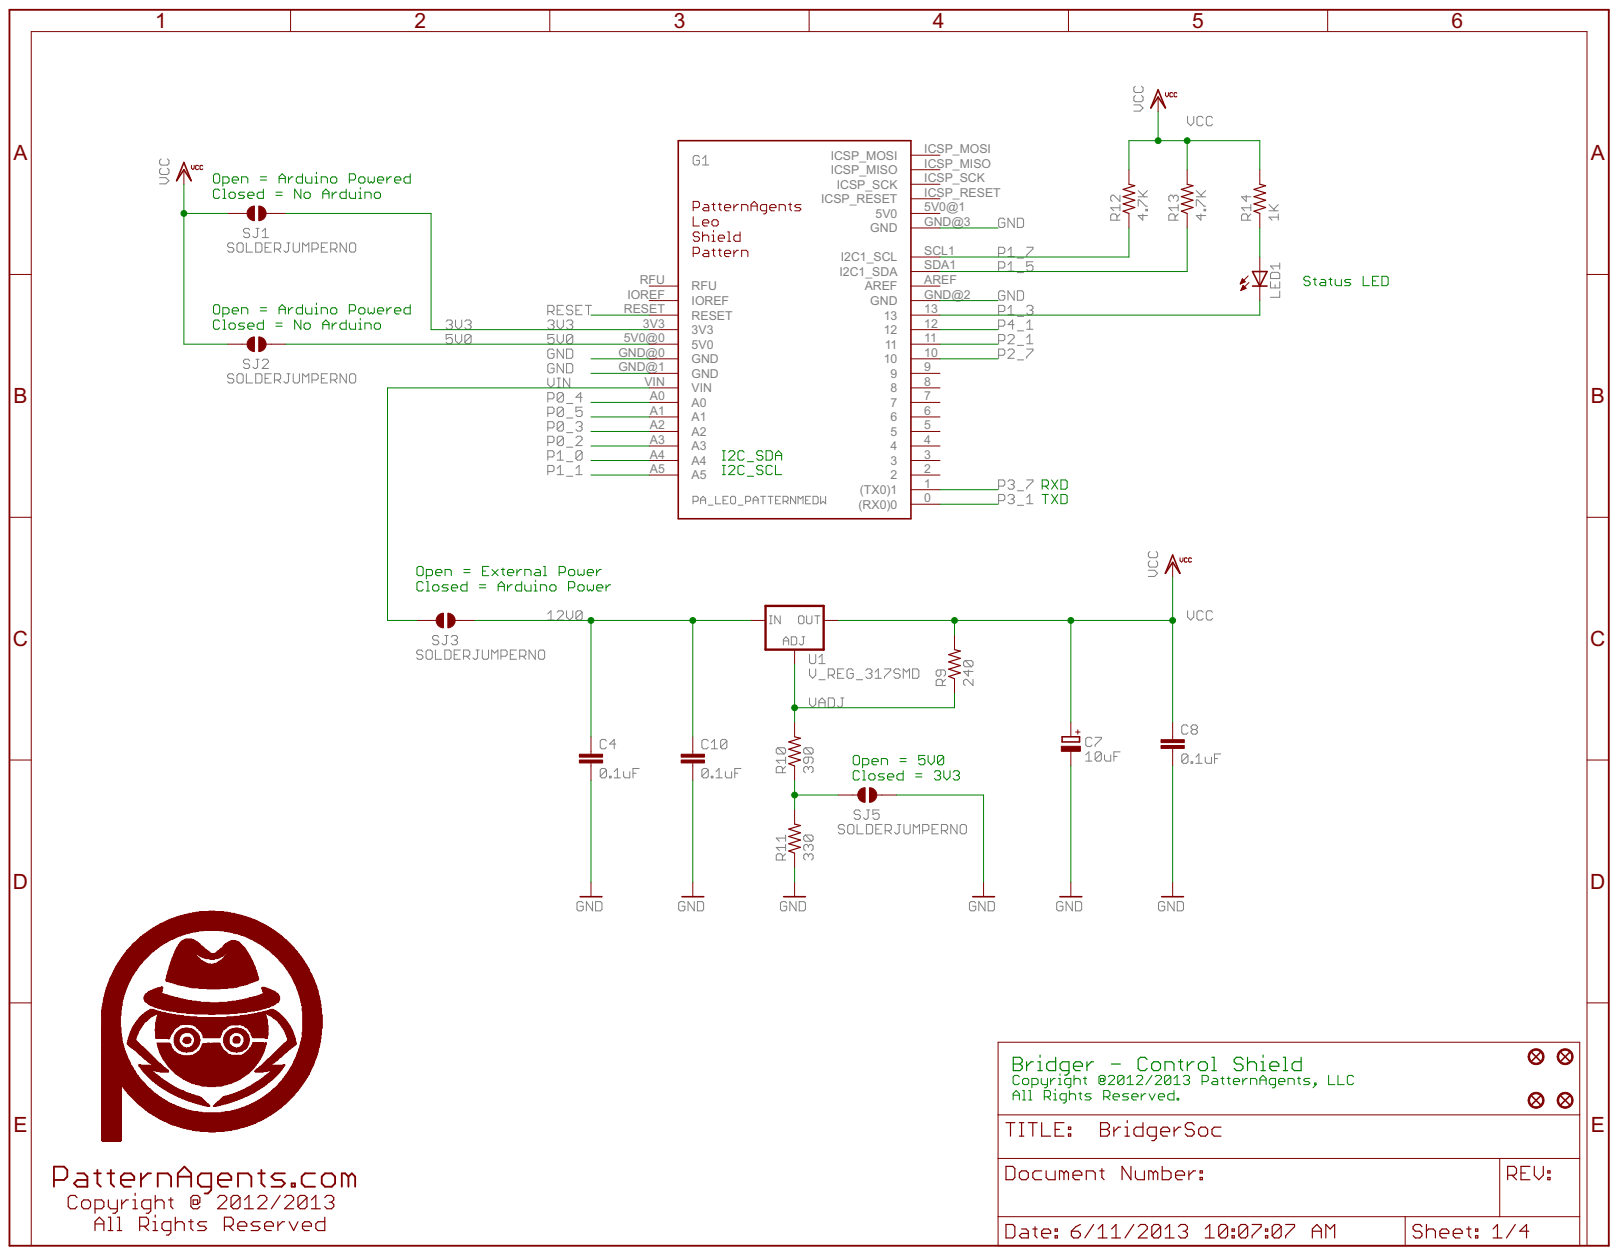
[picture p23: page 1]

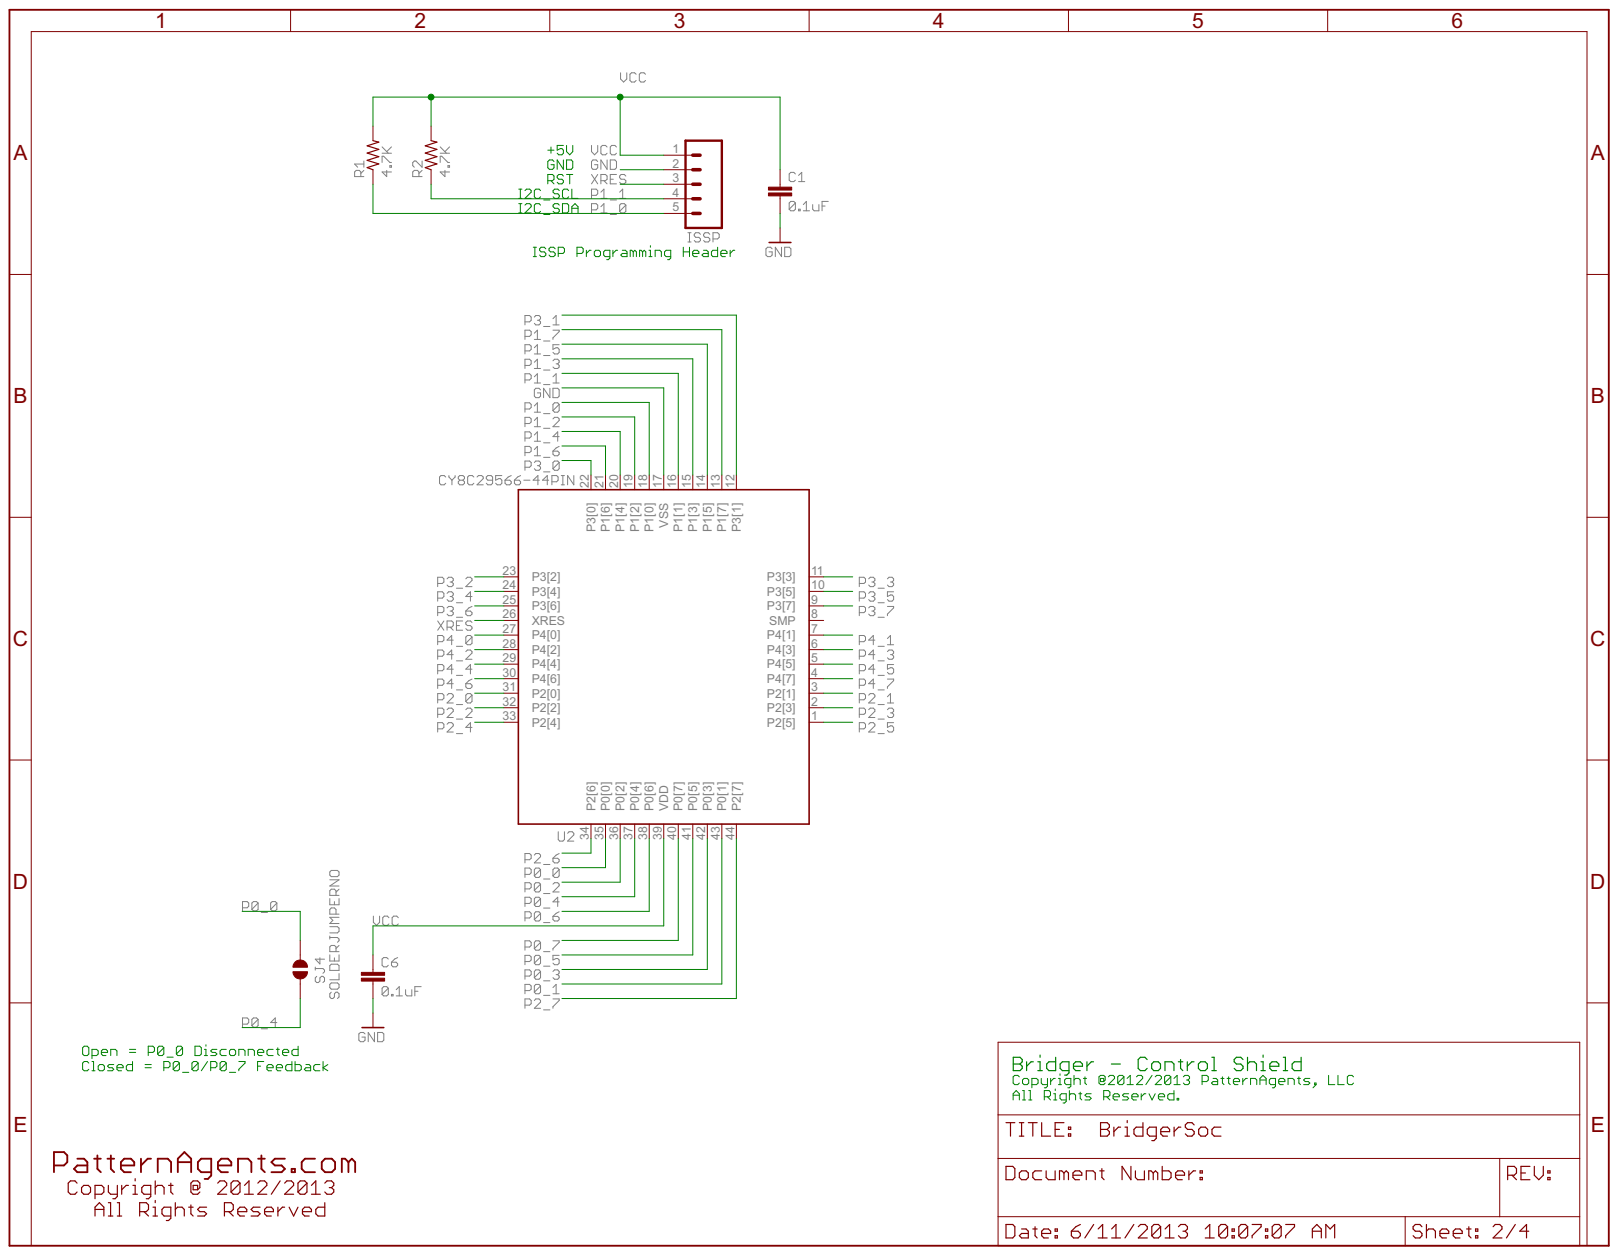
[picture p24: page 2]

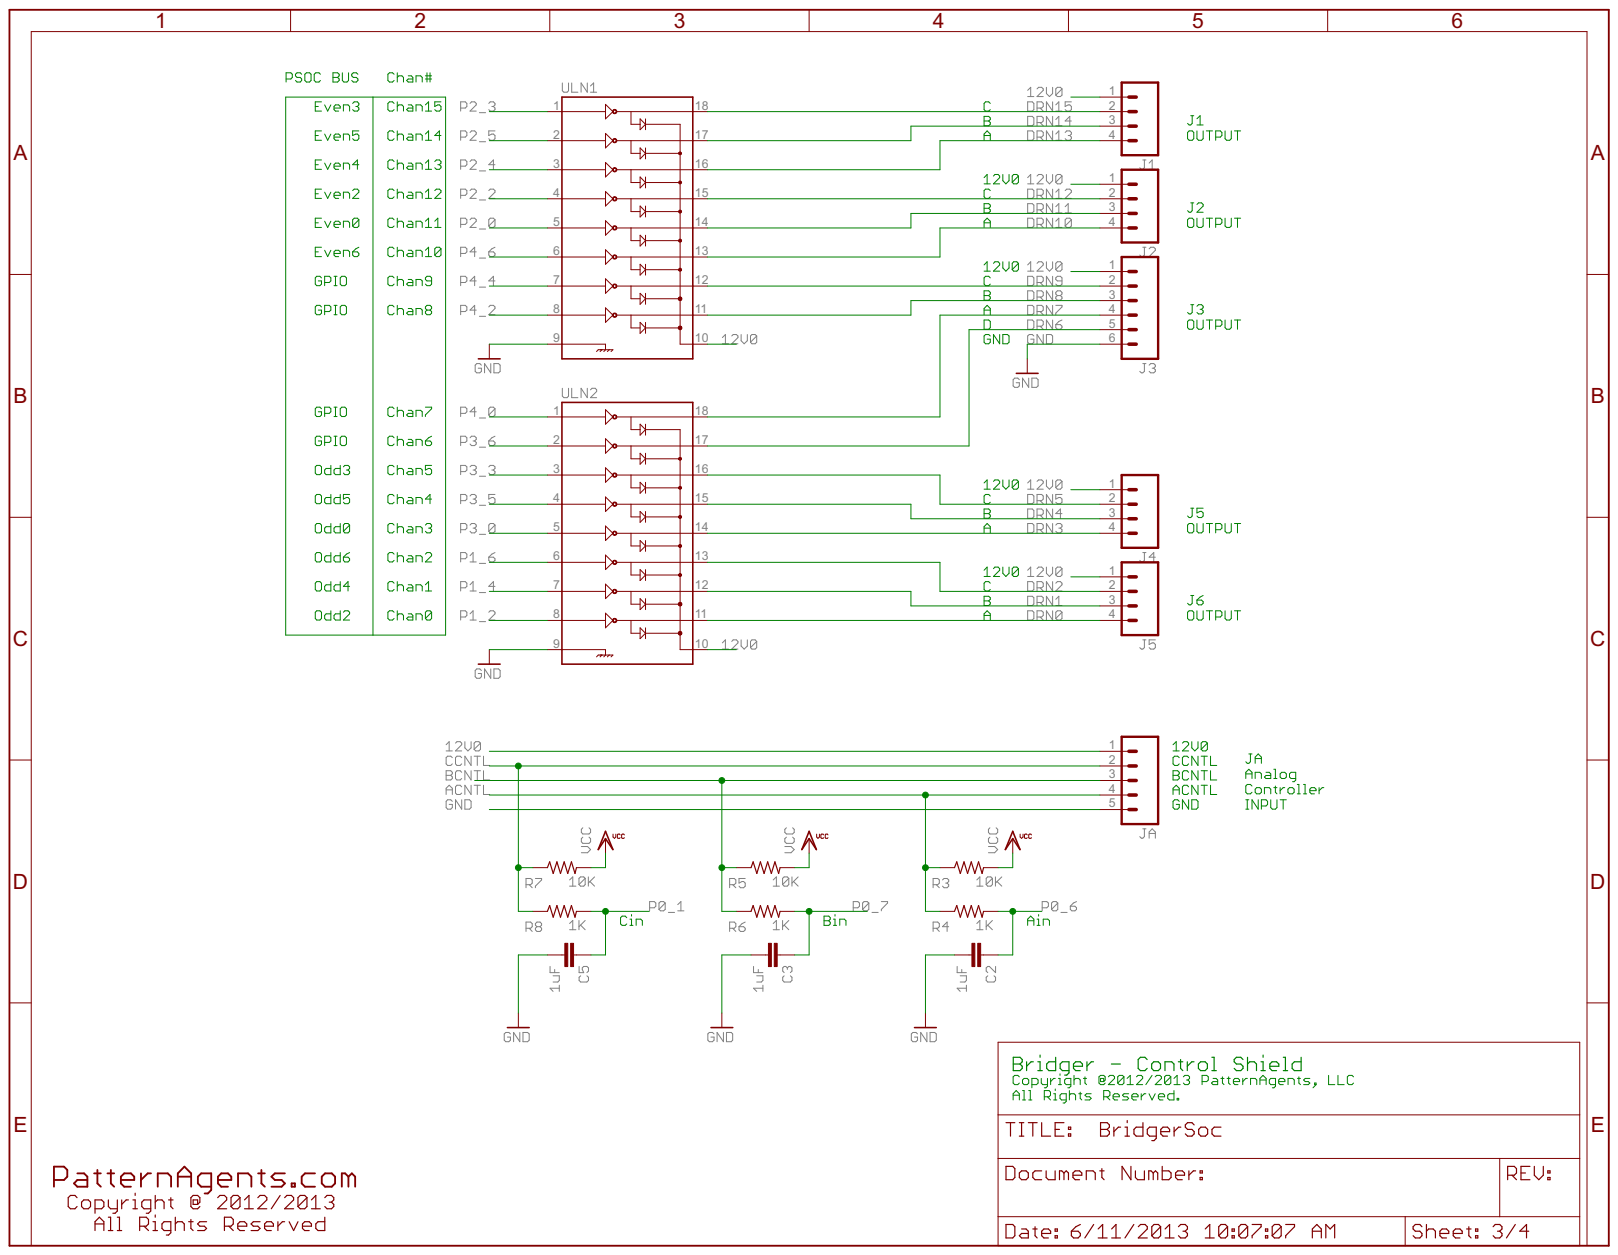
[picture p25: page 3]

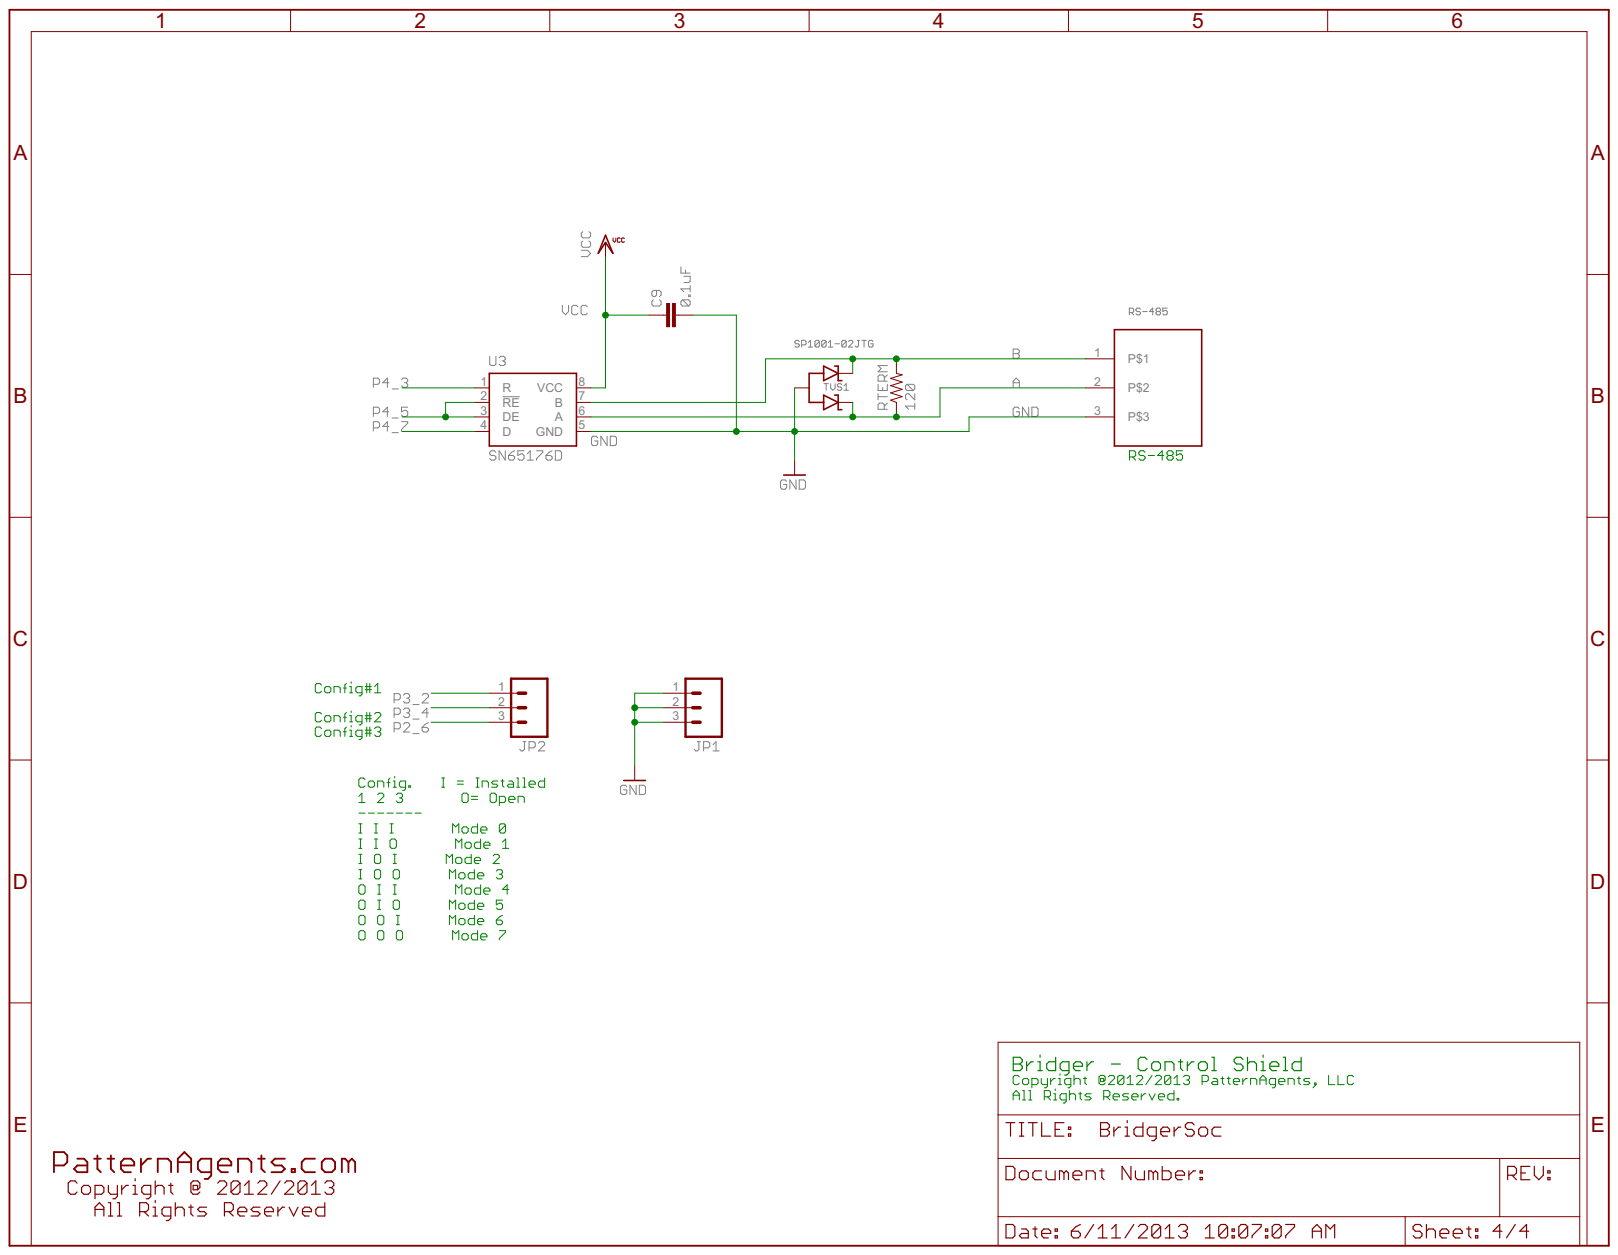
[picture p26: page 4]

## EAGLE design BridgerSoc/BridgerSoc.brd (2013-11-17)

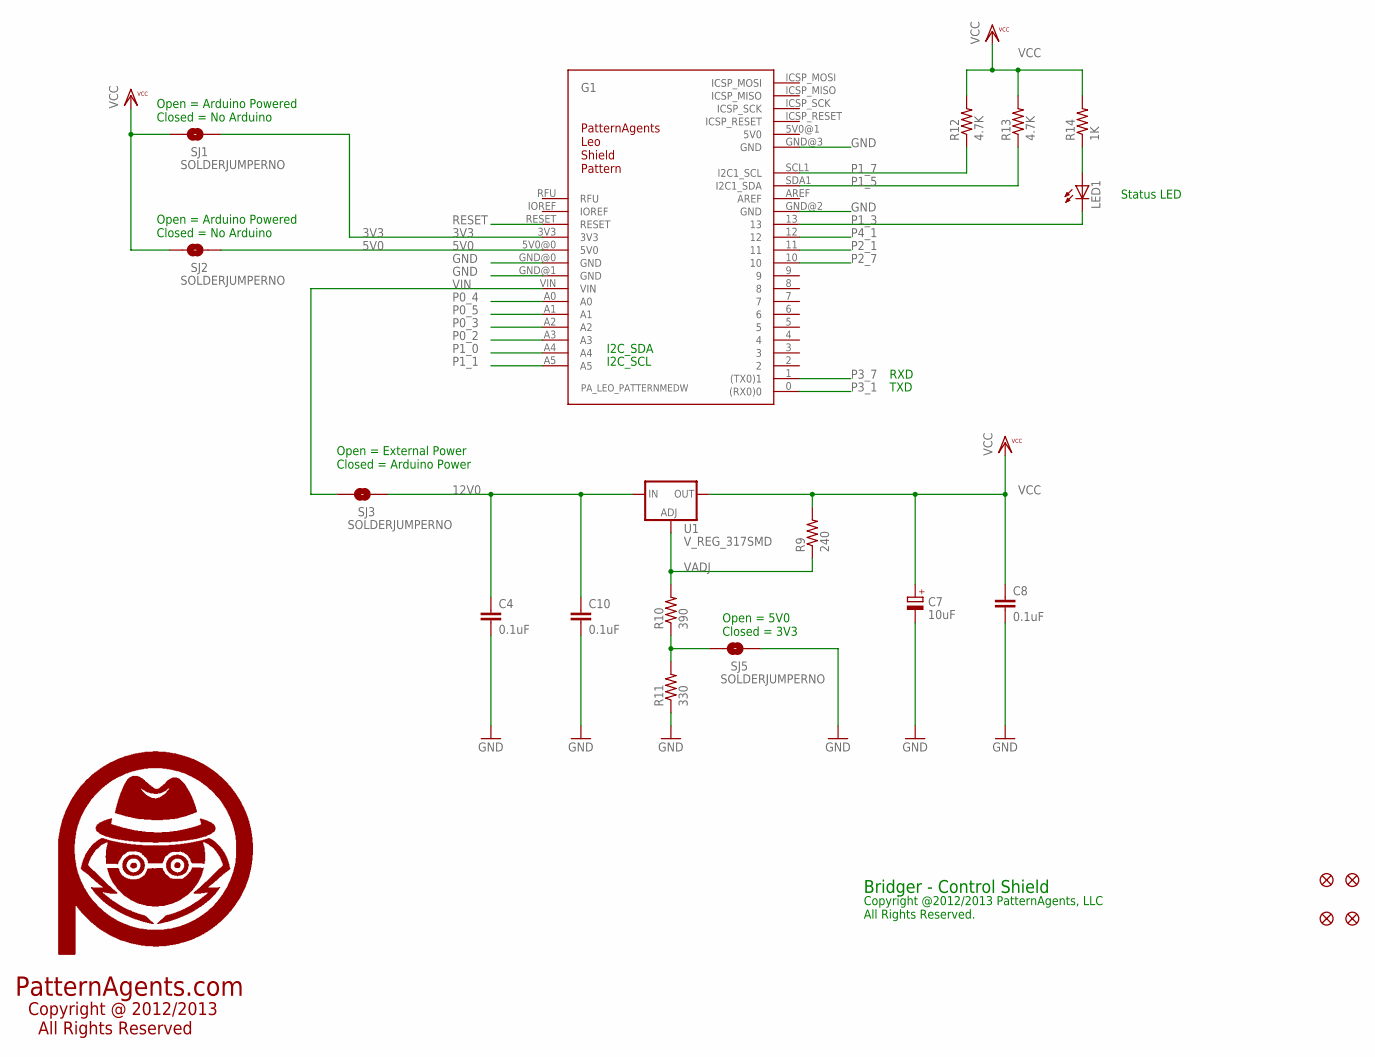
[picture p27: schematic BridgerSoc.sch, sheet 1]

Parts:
C4, C8, C10: 0.1uF; 0603-CAP
C7: 10uF; SMC_B
FID1, FID2, FID3, FID4: FIDUCIAL1.5X3; FIDUCIAL-1.5X3
G1: PA_LEO_PATTERNMEDW; PA_LEO_MEDW_PATTERN
LED1: LED0603; LED-0603
R9: 240; R0603
R10: 390; R0603
R11: 330; R0603
R12, R13: 4.7K; R0603
R14: 1K; R0603
SJ1, SJ2, SJ3, SJ5: SOLDERJUMPERNO; SJ_2S-NO
U1: V_REG_317SMD; SOT223
U$1: PA_LOGO_SYMLARGE; PA_LOGO_AGENT_LRG_SYM

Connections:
3V3: G1.3V3, SJ1.1
5V0: G1.5V0@0 (5V0), G1.5V0@1 (5V0), SJ2.1
12V0: C4.1, C10.1, SJ3.1, U1.3 (IN); also elsewhere on the board
GND: C4.2, C7.-, C8.2, C10.2, G1.GND@0 (GND), G1.GND@1 (GND), G1.GND@2 (GND), G1.GND@3 (GND), R11.1, SJ5.1; also elsewhere on the board
LED_D13: LED1.A, R14.1
P0_2: G1.A3; also elsewhere on the board
P0_3: G1.A2; also elsewhere on the board
P0_4: G1.A0; also elsewhere on the board
P0_5: G1.A1; also elsewhere on the board
P1_0: G1.A4; also elsewhere on the board
P1_1: G1.A5; also elsewhere on the board
P1_3: G1.13, LED1.C; also elsewhere on the board
P1_5: G1.SDA1 (I2C1_SDA), R13.1; also elsewhere on the board
P1_7: G1.SCL1 (I2C1_SCL), R12.1; also elsewhere on the board
P2_1: G1.11; also elsewhere on the board
P2_7: G1.10; also elsewhere on the board
P3_1: G1.0 ((RX0)0); also elsewhere on the board
P3_7: G1.1 ((TX0)1); also elsewhere on the board
P4_1: G1.12; also elsewhere on the board
RESET: G1.RESET
RFU: G1.RFU
V3_5: R10.1, R11.2, SJ5.2
VADJ: R9.1, R10.2, U1.1 (ADJ)
VCC: C7.+, C8.1, R9.2, R12.2, R13.2, R14.2, SJ1.2, SJ2.2, U1.2 (OUT); also elsewhere on the board
VIN: G1.VIN, SJ3.2

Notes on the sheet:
PatternAgents.com
Copyright @ 2012/2013 All Rights Reserved
Bridger - Control Shield
Copyright @2012/2013 PatternAgents, LLC All Rights Reserved.
I2C_SDA
I2C_SCL
Open = 5V0 Closed = 3V3
Open = External Power Closed = Arduino Power
Open = Arduino Powered Closed = No Arduino
TXD
RXD
Status LED

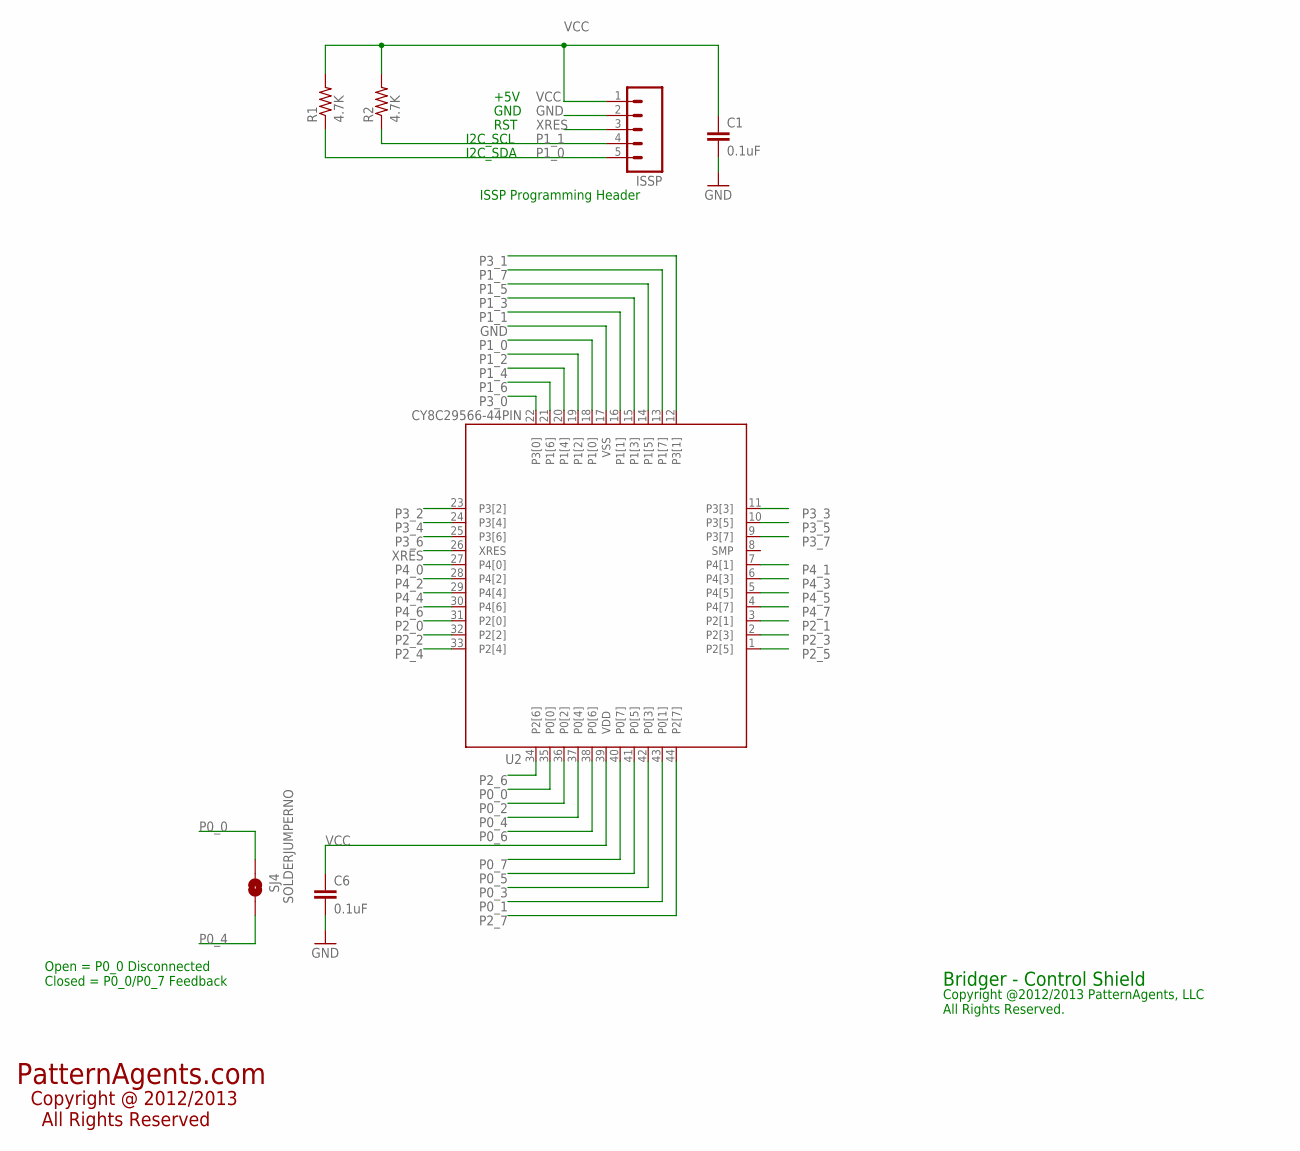
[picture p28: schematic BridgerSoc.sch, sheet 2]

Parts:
C1, C6: 0.1uF; 0603-CAP
ISSP: M05PTH; 1X05
R1, R2: 4.7K; R0603
SJ4: SOLDERJUMPERNO; SJ_2S-NO
U2: CY8C29566-44PIN; TQFP-10X10-44

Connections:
GND: C1.2, C6.2, ISSP.2, U2.17 (VSS); also elsewhere on the board
P0_0: SJ4.1, U2.35 (P0[0])
P0_1: U2.43 (P0[1]); also elsewhere on the board
P0_2: U2.36 (P0[2]); also elsewhere on the board
P0_3: U2.42 (P0[3]); also elsewhere on the board
P0_4: SJ4.2, U2.37 (P0[4]); also elsewhere on the board
P0_5: U2.41 (P0[5]); also elsewhere on the board
P0_6: U2.38 (P0[6]); also elsewhere on the board
P0_7: U2.40 (P0[7]); also elsewhere on the board
P1_0: ISSP.5, R1.1, U2.18 (P1[0]); also elsewhere on the board
P1_1: ISSP.4, R2.1, U2.16 (P1[1]); also elsewhere on the board
P1_2: U2.19 (P1[2]); also elsewhere on the board
P1_3: U2.15 (P1[3]); also elsewhere on the board
P1_4: U2.20 (P1[4]); also elsewhere on the board
P1_5: U2.14 (P1[5]); also elsewhere on the board
P1_6: U2.21 (P1[6]); also elsewhere on the board
P1_7: U2.13 (P1[7]); also elsewhere on the board
P2_0: U2.31 (P2[0]); also elsewhere on the board
P2_1: U2.3 (P2[1]); also elsewhere on the board
P2_2: U2.32 (P2[2]); also elsewhere on the board
P2_3: U2.2 (P2[3]); also elsewhere on the board
P2_4: U2.33 (P2[4]); also elsewhere on the board
P2_5: U2.1 (P2[5]); also elsewhere on the board
P2_6: U2.34 (P2[6]); also elsewhere on the board
P2_7: U2.44 (P2[7]); also elsewhere on the board
P3_0: U2.22 (P3[0]); also elsewhere on the board
P3_1: U2.12 (P3[1]); also elsewhere on the board
P3_2: U2.23 (P3[2]); also elsewhere on the board
P3_3: U2.11 (P3[3]); also elsewhere on the board
P3_4: U2.24 (P3[4]); also elsewhere on the board
P3_5: U2.10 (P3[5]); also elsewhere on the board
P3_6: U2.25 (P3[6]); also elsewhere on the board
P3_7: U2.9 (P3[7]); also elsewhere on the board
P4_0: U2.27 (P4[0]); also elsewhere on the board
P4_1: U2.7 (P4[1]); also elsewhere on the board
P4_2: U2.28 (P4[2]); also elsewhere on the board
P4_3: U2.6 (P4[3]); also elsewhere on the board
P4_4: U2.29 (P4[4]); also elsewhere on the board
P4_5: U2.5 (P4[5]); also elsewhere on the board
P4_6: U2.30 (P4[6]); also elsewhere on the board
P4_7: U2.4 (P4[7]); also elsewhere on the board
SMP: U2.8 (SMP)
VCC: C1.1, C6.1, ISSP.1, R1.2, R2.2, U2.39 (VDD); also elsewhere on the board
XRES: ISSP.3, U2.26 (XRES)

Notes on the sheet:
PatternAgents.com
Copyright @ 2012/2013 All Rights Reserved
Bridger - Control Shield
Copyright @2012/2013 PatternAgents, LLC All Rights Reserved.
ISSP Programming Header
I2C_SDA
I2C_SCL
RST
GND
+5V
Open = P0_0 Disconnected Closed = P0_0/P0_7 Feedback

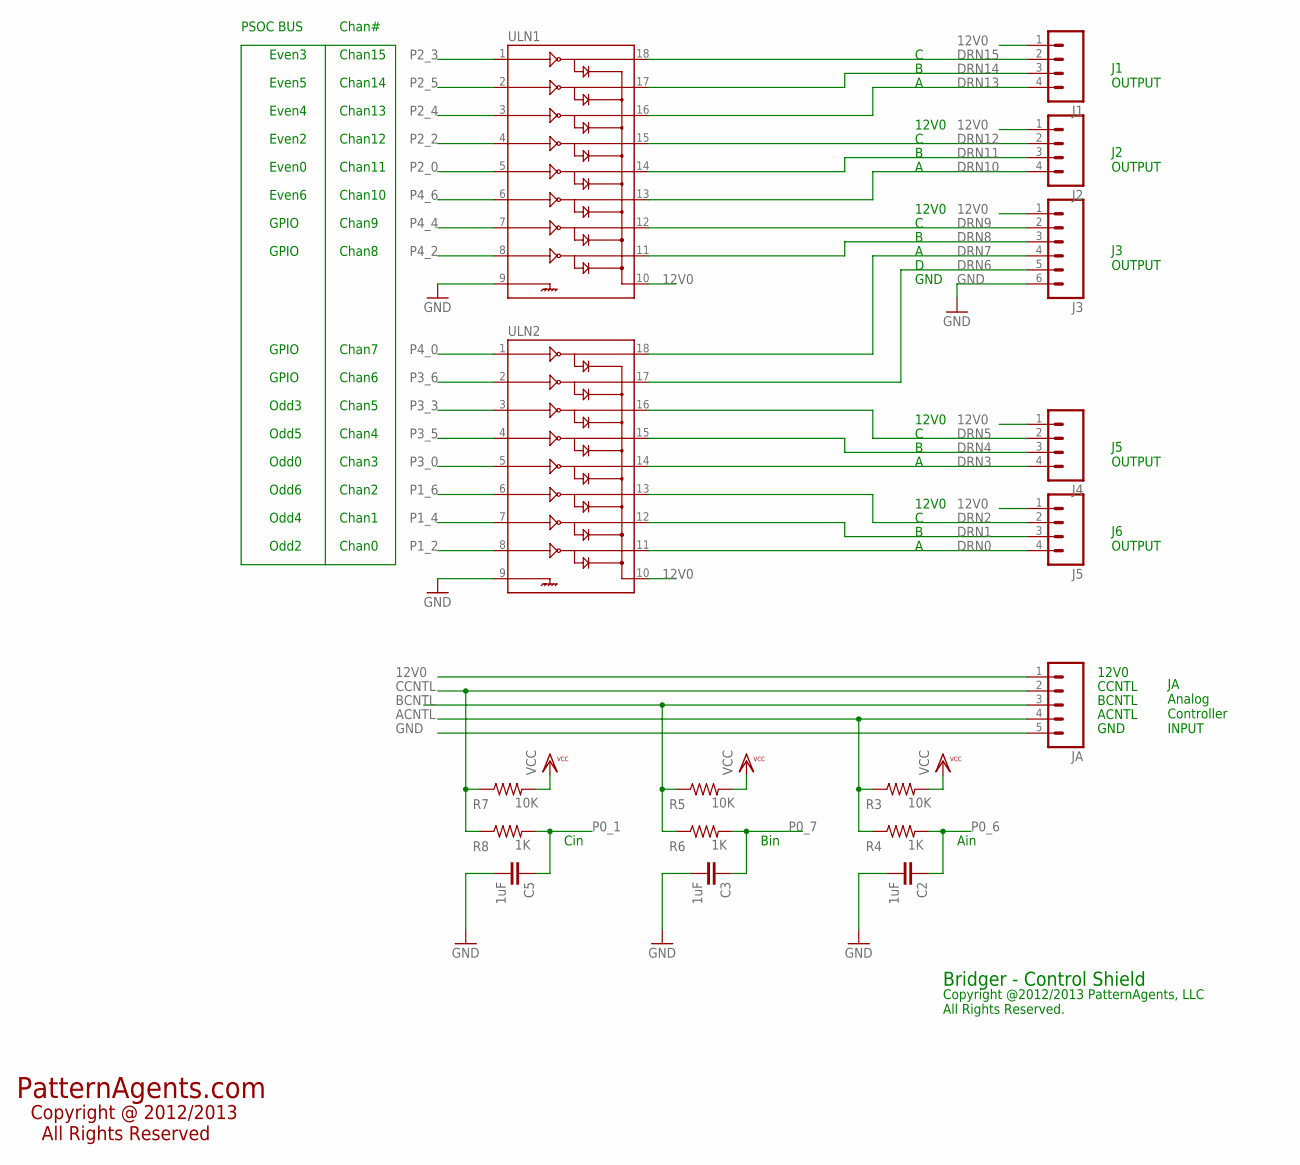
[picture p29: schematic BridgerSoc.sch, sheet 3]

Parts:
C2, C3, C5: 1uF; 0603-CAP
J1, J2, J4, J5: M04PTH; 1X04
J3: M06SIP; 1X06
JA: M05PTH; 1X05
R3, R5, R7: 10K; R0603
R4, R6, R8: 1K; R0603
ULN1, ULN2: ULN2803SOICW; SO18L

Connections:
12V0: J1.1, J2.1, J3.1, J4.1, J5.1, JA.1, ULN1.10, ULN2.10; also elsewhere on the board
ACNTL: JA.4, R3.1, R4.1
BCNTL: JA.3, R5.1, R6.1
CCNTL: JA.2, R7.1, R8.1
DRN0: J5.4, ULN2.11
DRN1: J5.3, ULN2.12
DRN2: J5.2, ULN2.13
DRN3: J4.4, ULN2.14
DRN4: J4.3, ULN2.15
DRN5: J4.2, ULN2.16
DRN6: J3.5, ULN2.17
DRN7: J3.4, ULN2.18
DRN8: J3.3, ULN1.11
DRN9: J3.2, ULN1.12
DRN10: J2.4, ULN1.13
DRN11: J2.3, ULN1.14
DRN12: J2.2, ULN1.15
DRN13: J1.4, ULN1.16
DRN14: J1.3, ULN1.17
DRN15: J1.2, ULN1.18
GND: C2.2, C3.2, C5.2, J3.6, JA.5, ULN1.9, ULN2.9; also elsewhere on the board
P0_1: C5.1, R8.2; also elsewhere on the board
P0_6: C2.1, R4.2; also elsewhere on the board
P0_7: C3.1, R6.2; also elsewhere on the board
P1_2: ULN2.8; also elsewhere on the board
P1_4: ULN2.7; also elsewhere on the board
P1_6: ULN2.6; also elsewhere on the board
P2_0: ULN1.5; also elsewhere on the board
P2_2: ULN1.4; also elsewhere on the board
P2_3: ULN1.1; also elsewhere on the board
P2_4: ULN1.3; also elsewhere on the board
P2_5: ULN1.2; also elsewhere on the board
P3_0: ULN2.5; also elsewhere on the board
P3_3: ULN2.3; also elsewhere on the board
P3_5: ULN2.4; also elsewhere on the board
P3_6: ULN2.2; also elsewhere on the board
P4_0: ULN2.1; also elsewhere on the board
P4_2: ULN1.8; also elsewhere on the board
P4_4: ULN1.7; also elsewhere on the board
P4_6: ULN1.6; also elsewhere on the board
VCC: R3.2, R5.2, R7.2; also elsewhere on the board

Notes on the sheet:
Bridger - Control Shield
Copyright @2012/2013 PatternAgents, LLC All Rights Reserved.
PatternAgents.com
Copyright @ 2012/2013 All Rights Reserved
12V0
GND
ACNTL
BCNTL
CCNTL
JA Analog Controller INPUT
J6 OUTPUT
J5 OUTPUT
J3 OUTPUT
J2 OUTPUT
J1 OUTPUT
Cin
Bin
Ain
Chan0
Chan1
Chan2
Chan3
Chan4
Chan5
Chan6
Chan7
Chan8
Chan9
Chan10
Chan11
Chan12
Chan13
Chan14
Chan15
Odd2
Odd4
Odd6
Odd0
Odd3
Odd5

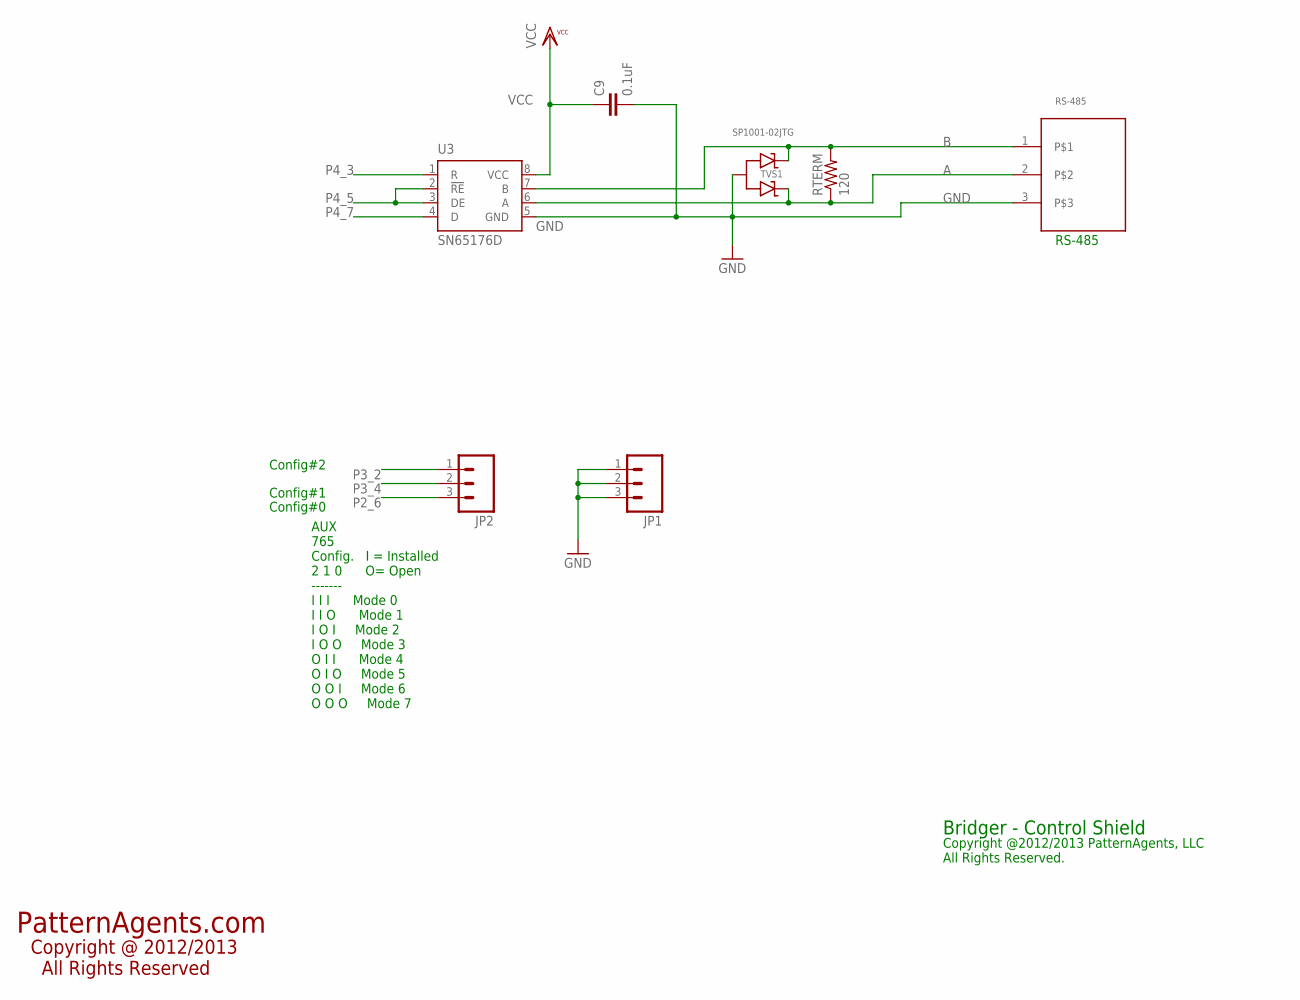
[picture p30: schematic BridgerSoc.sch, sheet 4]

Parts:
C9: 0.1uF; 0603-CAP
JP1, JP2: M03PTH; 1X03
RS-485: 70553-02
RTERM: 120; 0603-RES
TVS1: SP1001-02JTG; SC70-3
U3: SN65176D; SO-08

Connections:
A: RS-485.2, RTERM.1, TVS1.2 (C2), U3.6 (A)
B: RS-485.1, RTERM.2, TVS1.1 (C1), U3.7 (B)
GND: C9.2, JP1.1, JP1.2, JP1.3, RS-485.3, TVS1.3 (A), U3.5 (GND); also elsewhere on the board
P2_6: JP2.3; also elsewhere on the board
P3_2: JP2.1; also elsewhere on the board
P3_4: JP2.2; also elsewhere on the board
P4_3: U3.1 (R); also elsewhere on the board
P4_5: U3.2 (!RE), U3.3 (DE); also elsewhere on the board
P4_7: U3.4 (D); also elsewhere on the board
VCC: C9.1, U3.8 (VCC); also elsewhere on the board

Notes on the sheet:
RS-485
PatternAgents.com
Copyright @ 2012/2013 All Rights Reserved
Bridger - Control Shield
Copyright @2012/2013 PatternAgents, LLC All Rights Reserved.
Config#2
Config#1
Config#0
AUX 765 Config. I = Installed 2 1 0 O= Open ------- I I I Mode 0 I I O Mode 1 I O I Mode 2 I O O Mode 3 O I I Mode 4 O I O Mode 5 O O I Mode 6 O O O Mode 7

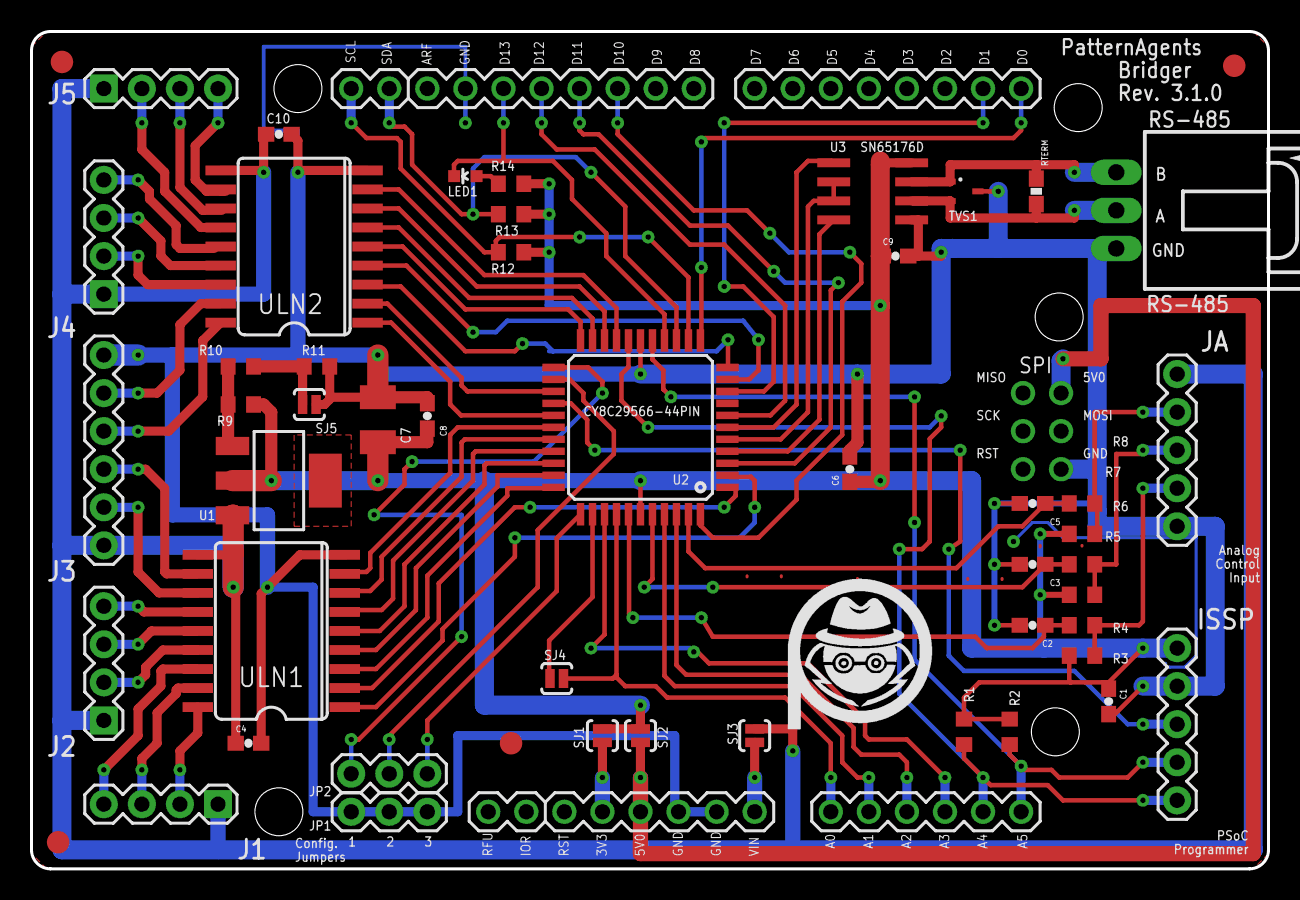
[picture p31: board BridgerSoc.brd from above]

Board: 2 copper layers, 82.6 x 55.9 mm, 54 parts (1 on the bottom side), 71 nets.

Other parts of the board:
U$9: PA_LOGO_AGENT_LRG_SYM

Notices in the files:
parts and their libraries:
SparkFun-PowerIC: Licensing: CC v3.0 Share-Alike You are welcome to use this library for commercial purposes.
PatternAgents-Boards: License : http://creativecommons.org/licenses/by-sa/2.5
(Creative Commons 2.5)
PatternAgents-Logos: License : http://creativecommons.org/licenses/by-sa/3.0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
